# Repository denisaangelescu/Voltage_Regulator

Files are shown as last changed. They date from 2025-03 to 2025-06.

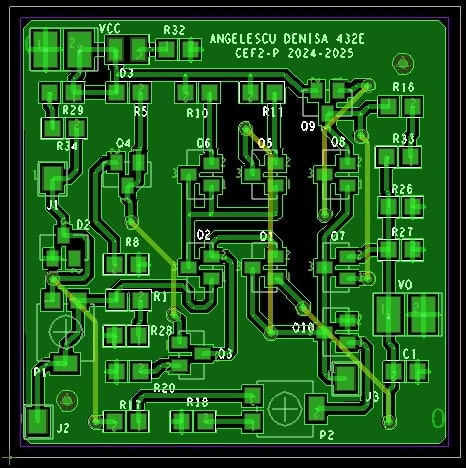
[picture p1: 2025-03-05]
Layout/layout.jpg

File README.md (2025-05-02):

Designed a voltage stabilizer with a series regulation element, ensuring an adjustable output voltage (2V-2.5V) with low thermal drift (<2mV/°C) and high open-loop gain (>200) for stability and precision. The circuit includes short-circuit and thermal protection, limiting the regulation transistor’s temperature to 100°C and the maximum current to 0.4A. Manually calculated component values, performed analytical validation, and simulated the design in OrCAD. Created a PCB layout with SMD components, awaiting fabrication for physical testing.

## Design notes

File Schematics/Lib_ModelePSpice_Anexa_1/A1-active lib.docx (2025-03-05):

77 | 4148 | (LINK) (http://www.tme.eu/ro/details/1n4148-0805/diode-universale-smd/dc-components/cd4148ws0805c/) | 1N4148-0805
79 | 2.7V | (LINK) (http://www.tme.eu/ro/details/bzx84c2v7/diode-zener-smd/on-semiconductor/bzx84c2v7lt1g/) | BZX84C2V7
80 | 5.1V | (LINK) (http://www.tme.eu/ro/details/bzx84c5v1/diode-zener-smd/nxp/bzx84-c5v1215/) | BZX84C5V1
81 | 5.6V | (LINK) (http://www.tme.eu/ro/details/bzx84c5v6/diode-zener-smd/nxp/bzx84-c5v6215/) | BZX84C5V6
82 | 6.2V | (LINK) (http://www.tme.eu/ro/details/bzx84c6v2/diode-zener-smd/nxp/bzx84-c6v2215/) | BZX84C6V2
83 | 6.8V | (LINK) (http://www.tme.eu/ro/details/bzx84c6v8/diode-zener-smd/nxp/bzx84-c6v8215/) | BZX84C6V8
84 | 8.2V | (LINK) (http://www.tme.eu/ro/details/bzx84c8v2/diode-zener-smd/nxp/bzx84-c8v2215/) | BZX84C8V2
85 | 10V | (LINK) (http://www.tme.eu/ro/details/bzx84c10/diode-zener-smd/nxp/bzx84-c10215/) | BZX84C10
86 | PNP | (LINK) (http://www.tme.eu/ro/details/bc856b.215/tranzistori-smd-pnp/nxp/) | BC856B
87 | NPN | (LINK) (http://www.tme.eu/ro/details/bc846b.215/tranzistori-smd-npn/nxp/) | BC846B
89 | N-JFET | (LINK) (http://www.tme.eu/ro/details/mmbfj309lt1g/tranzistori-canal-n-smd/on-semiconductor/) | MMBFJ309LT1G
90 | P-JFET | (LINK) (http://www.tme.eu/ro/details/mmbfj177lt1g/tranzistori-canal-p-smd/on-semiconductor/) | MMBFJ177LT1G
91 | NPN | (LINK) (http://www.tme.eu/ro/details/bc817-25-dio/tranzistori-smd-npn/diotec-semiconductor/bc817-25/) | BC817-25-DIO
93 | PNP | (LINK) (http://www.tme.eu/ro/details/bc807-25-dio/tranzistori-smd-pnp/diotec-semiconductor/bc807-25/) | BC807-25-DIO
94 | NPN | (LINK) (http://www.tme.eu/ro/details/mjd31cg/tranzistori-smd-npn/on-semiconductor/) | MJD31CG
96 | PNP | (LINK) (http://www.tme.eu/ro/details/mjd32cg/tranzistori-smd-pnp/on-semiconductor/) | MJD32CG
97 | Nmos | (LINK) (http://www.tme.eu/ro/details/irfr120npbf/tranzistori-canal-n-smd/international-rectifier/) | IRFR120NPBF

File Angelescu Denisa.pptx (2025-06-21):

## Circuite Electronice Fundamentale 2 – Proiect (CEF2-Pr)

Tema: Stabilizator de tensiune cu ERS

Student: Angelescu Denisa Grupa 432E

## Date de proiectare

Să se proiecteze și realizeze un stabilizator de tensiune cu ERS având următoarele caracteristici:
N = 1
- Tensiunea de ieșire reglabilă în intervalul: - 2 ÷ 2,5 [V]
- Element de reglaj serie;
- Sarcina la ieșire 50[Ω];
- Deriva termică < 2mV/˚C;
- Protecție la suprasarcină prin limitarea temperaturii tranzistorului element de reglaj serie la 100 ˚C și a curentului maxim la 0,4A;
- Tensiune de intrare în intervalul: - 4 ÷ 4,5 [V]
- Domeniul temperaturilor de funcționare: 0 ÷ 70 ˚C (verificabil prin testare în temperatură);
- Amplificarea în tensiune minimă (în buclă deschisă) a amplificatorului de eroare: minim 200;
- Semnalizarea prezenței tensiunilor de intrare/ieșire cu diodă de tip LED.

## Schema bloc

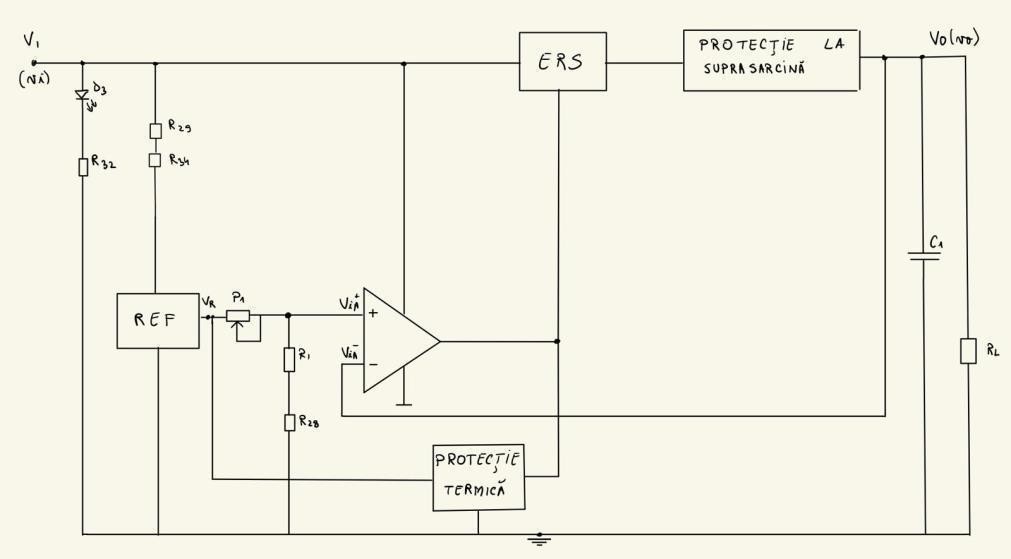
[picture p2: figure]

- D3, R32: Led de semnalizare, indică prezența tensiunii de intrare
- R29, R43: Asigură curentul minim prin REF
- REF (Referință de Tensiune): Creează o tensiune stabilă utilizată ca referința pentru comparație în amplificatorul de eroare
- P1, R1, R28: Divizor de tensiune

- Amplificator de eroare: Compară fracțiunea din tensiunea de ieșire cu tensiunea REF și generează un semnal pentru a controla elementul de reglare
- ERS (Element de reglare în serie): Reglează tensiunea de ieșire în funcție de semnalul primit de la amplificatorul de eroare
- Protecție termică: Protejează circuitul prin dezactivarea acestuia dacă temperatura depășește un nivel critic
- Protecție la suprasarcină: Previne deteriorarea circuitului prin limitarea curentului atunci când acesta depășește un prag specific
- Condensatorul C1: Stabilizează tensiunea de ieșire, eliminând fluctuațiile rapide sau variațiile datorate încărcării sarcinii

## Schema electrică

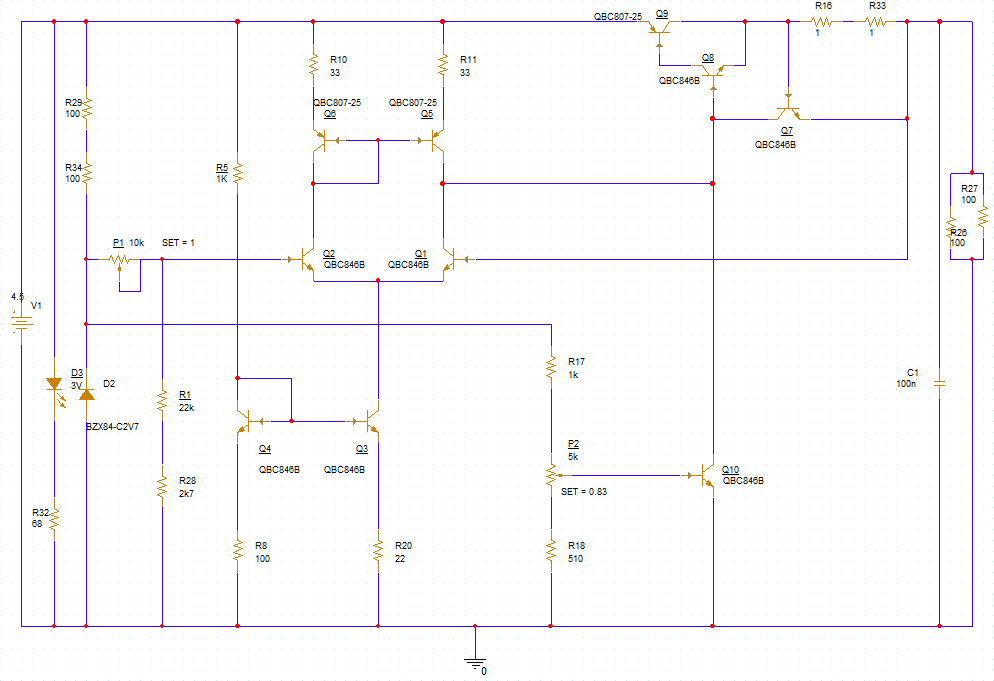
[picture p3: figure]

Reacția este realizată printr-un fir, iar tensiunea de la baza tranzistorului de control este direct legată de tensiunea de ieșire. Diferența dintre tensiunile din bazele tranzistorilor din intrările diferențiale creează un dezechilibru în curenții lor, care ajusteaza ERS pentru a stabiliza tensiunea de ieșire. Perechea Sziklai este mai eficientă decât Darlington pentru tensiuni mici, datorită căderii de tensiune mai reduse (0.6V față de 1.2V)

## Simulări

Tensiuni

Curenți

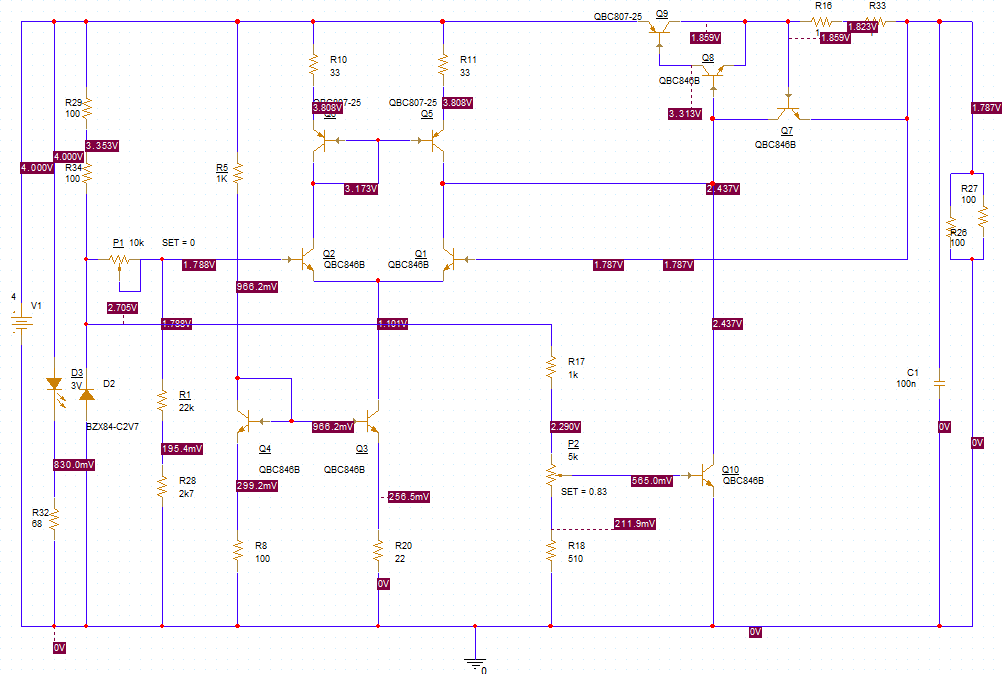
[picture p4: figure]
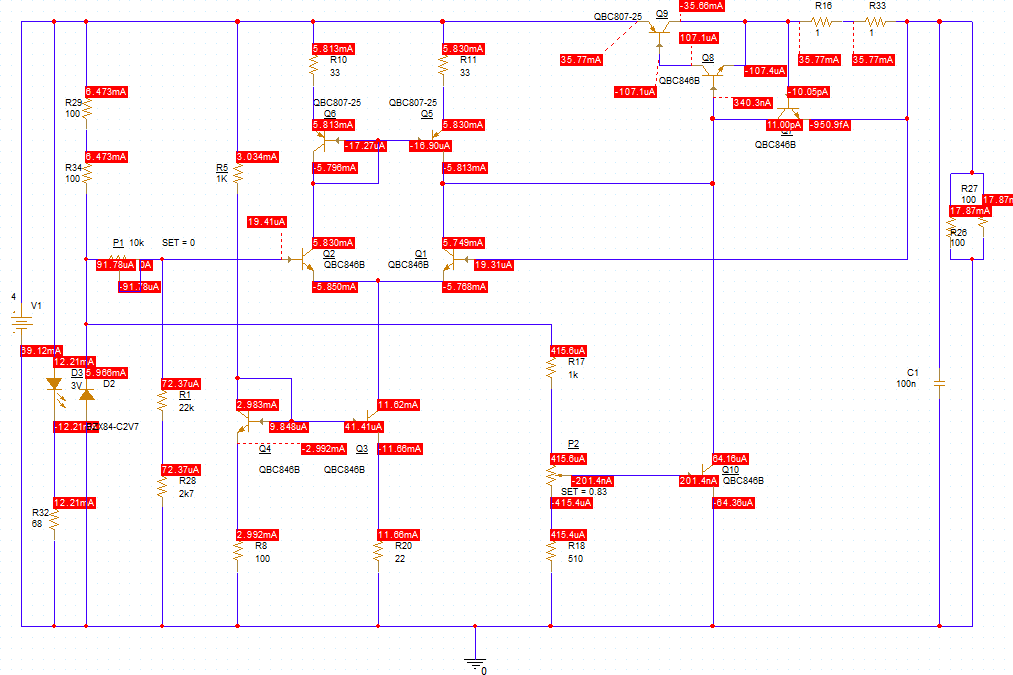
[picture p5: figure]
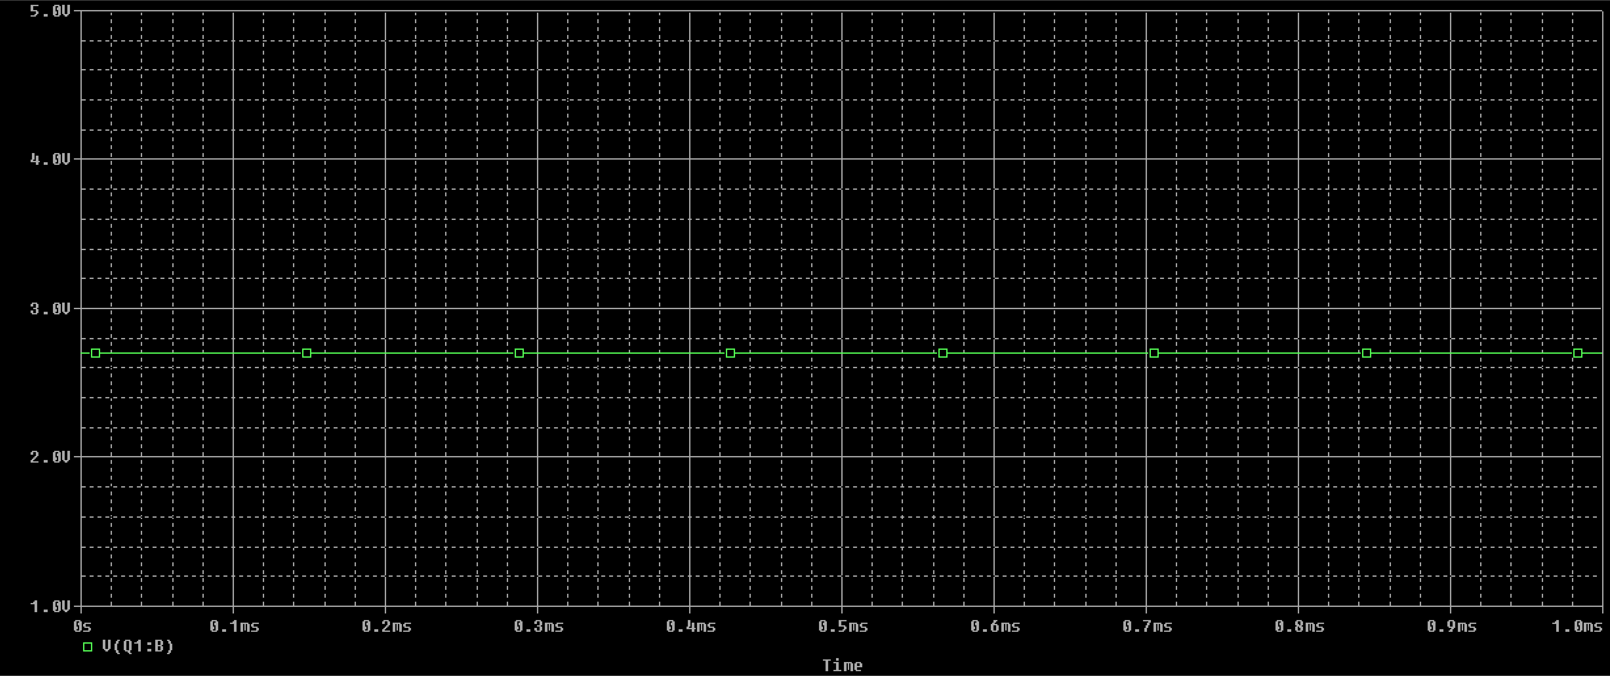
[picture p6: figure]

Variația Vout în timp

## Simulări

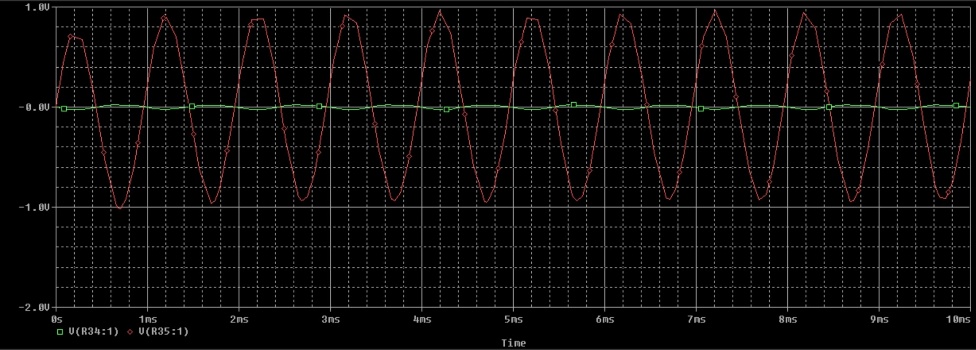
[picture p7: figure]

PSRR

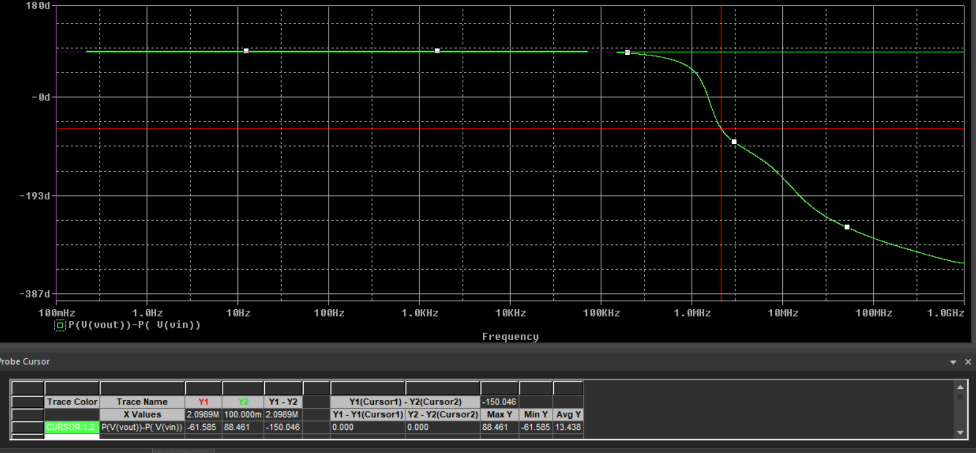
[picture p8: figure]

Faza amplificării

## Layout

Potențiometrele au fost poziționate la marginea plăcii pentru a permite reglaj ușor, fără a interveni în alte zone ale circuitului, iar conectorii de intrare și ieșire sunt amplasați pe exterior pentru măsurători simple și conectare rapidă. Tranzistoarele sunt centralizate și plasate aproape unele de altele pentru a menține caracteristici termice uniforme și a evita variațiile de funcționare. Pentru a reduce pierderile de semnal și interferențele, componentele critice, precum dioda Zener și rezistorii de referință, sunt plasate aproape de amplificatorul diferențial.
Am ales un traseu cu lățime de 18 mils pentru a evita supraîncălzirea și deteriorarea placii. Traseele mai late reduc impedanța și îmbunătățesc stabilitatea semnalelor, asigurând o funcționare mai precisă a circuitului.

Top

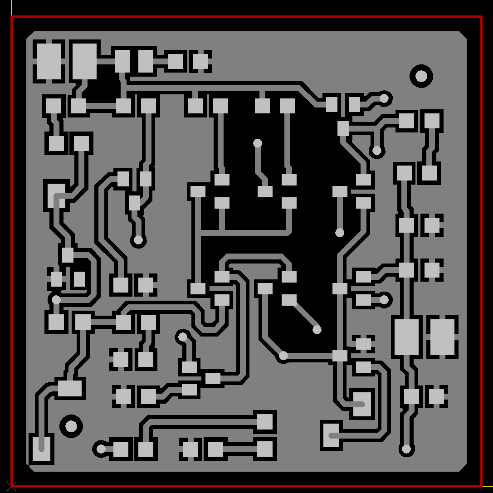
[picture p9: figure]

Bottom

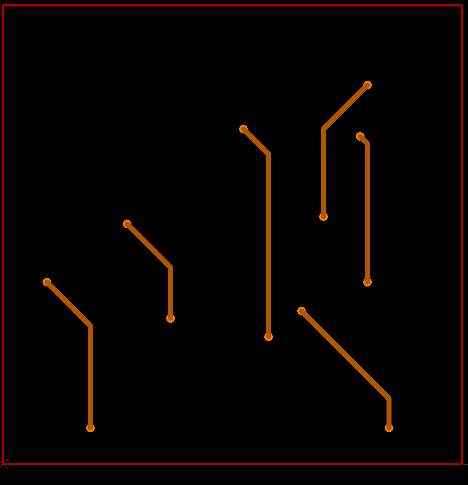
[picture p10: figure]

## Fotografii din etapa de echipare a modulului electronic

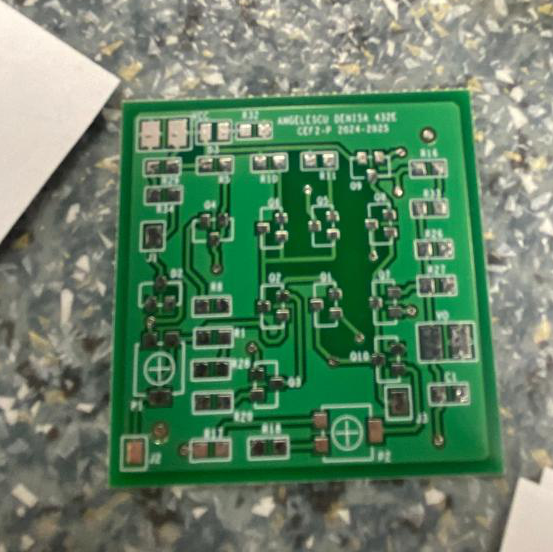
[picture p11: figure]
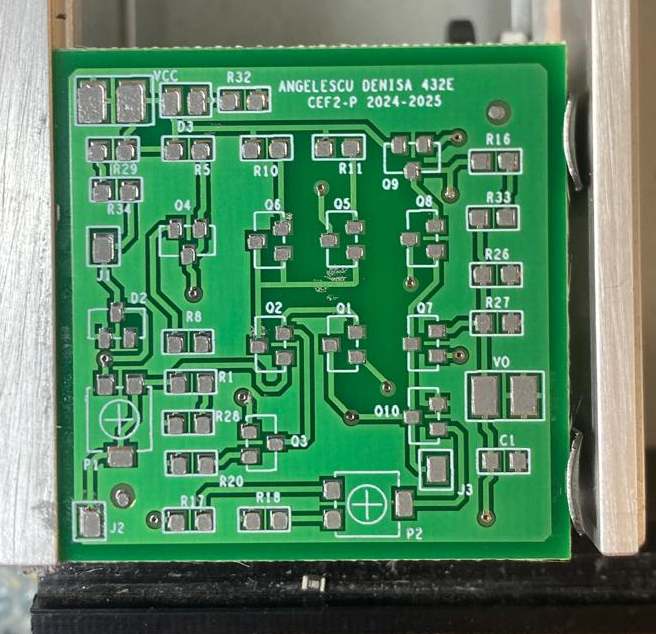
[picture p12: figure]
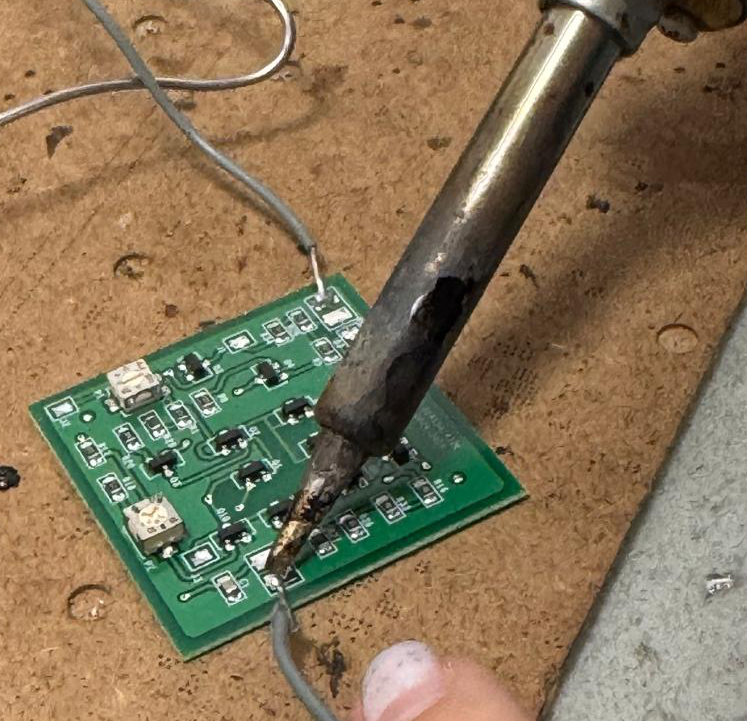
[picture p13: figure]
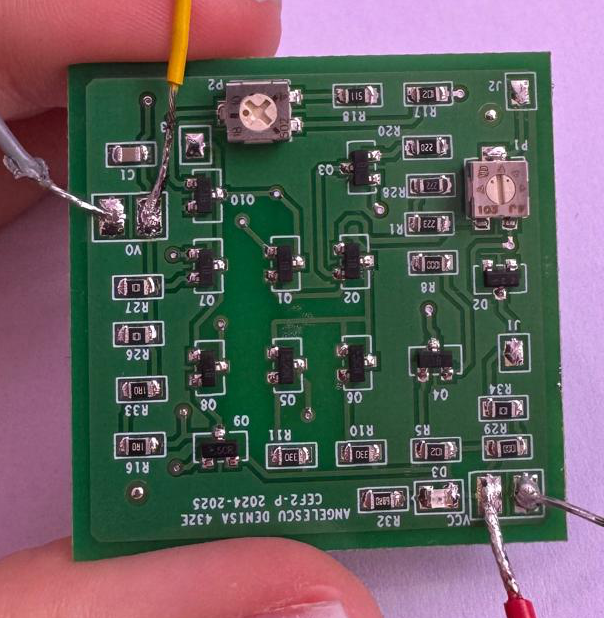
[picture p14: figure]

## Rezultate experimentale

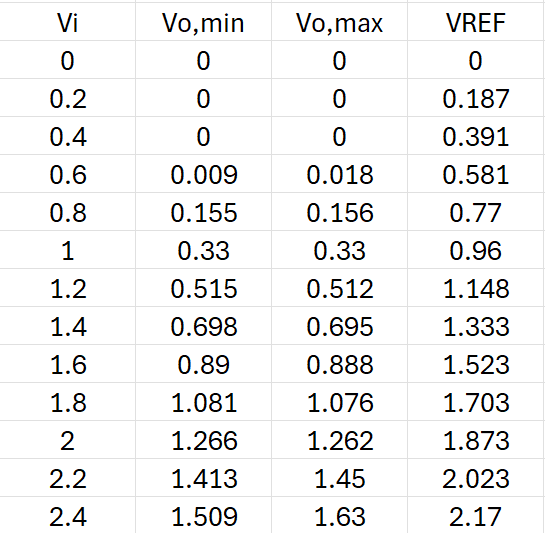
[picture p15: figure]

## Rezultate experimentale

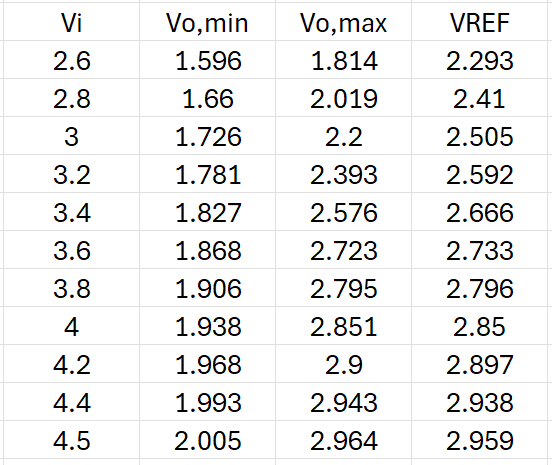
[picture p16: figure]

## Rezultate experimentale

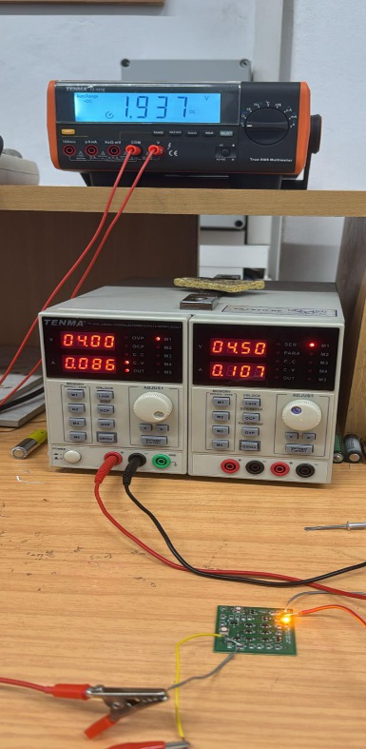
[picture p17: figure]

Vi=4V SET P1 = 0

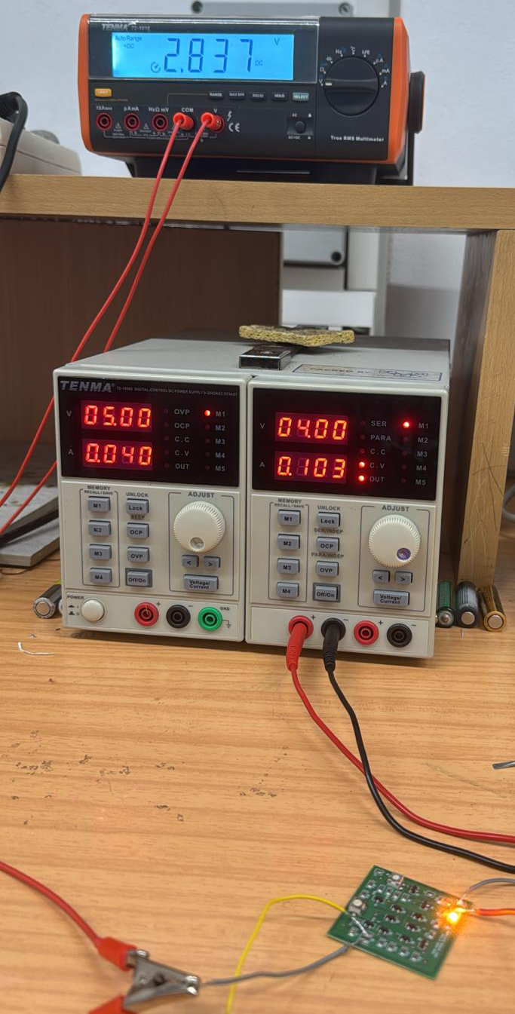
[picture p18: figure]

Vi=4V SET P1 = 1

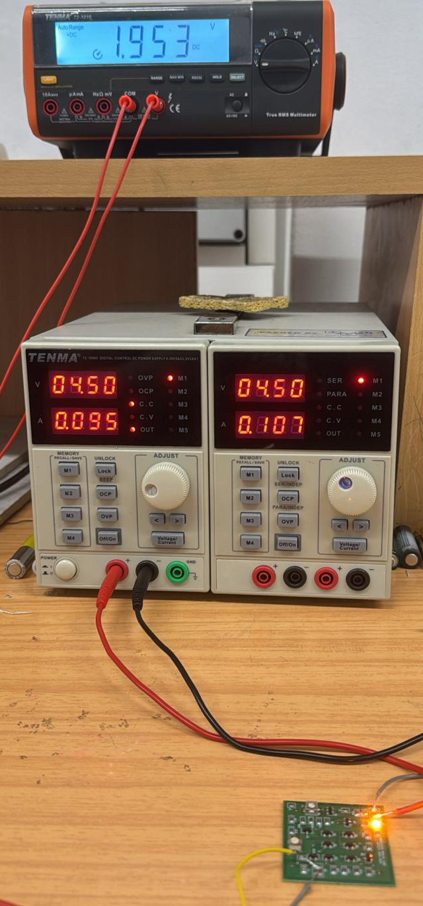
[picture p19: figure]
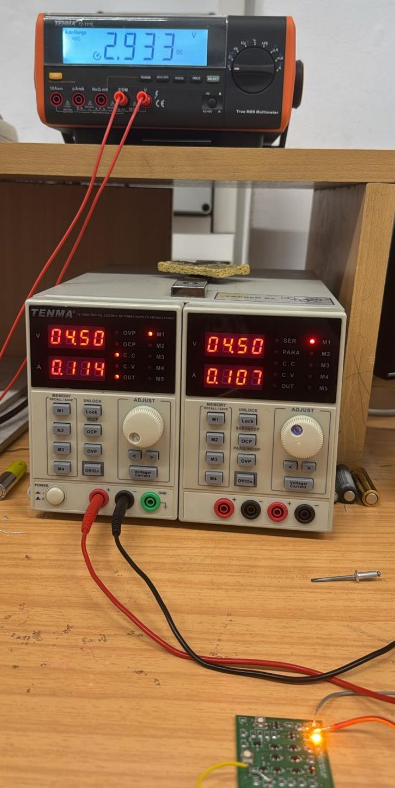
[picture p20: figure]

Vi=4V SET P1 = 0

Vi=4V SET P1 = 0

## Rezultate experimentale

- Tabel comparativ

Cerințe impuse | Rezultate simulări | Rezultate măsurători
OUT: 2 ÷ 2.5V | 1.75 ÷ 2.71V | 1.938 ÷ 2.964V
Deriva termică: 2mV/˚C | 0.3mV/˚C
Protecție limitarea temperaturii: 100˚C | 105˚C
Curent maxim: 0.4A | 0.37A
Amplificare buclă deschisă: 200 | 1163

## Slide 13

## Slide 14

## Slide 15

## Concluzii

- În urma folosirii unei diode mai mare de 2.7V, tensiunea de ieșire a avut o altă valoare față de intervalul specificat de temă.
- Din cauza toleranțelor dispozitivelor, există mici variații între valorile obținute în simulator și cele obținute în realitate.
- O îmbunătățire a proiectului constă în folosirea unor dispozitive cu toleranțe mult mai mici, care să nu influențeze atât de mult valorile reale.

## Cunoștințe dobândite:

- Competențe de simulare în Orcad: realizarea schemei electrice, setarea condițiilor inițiale și interpretarea corectă a rezultatelor.
- Proiectarea PCB-ului: amplasarea componentelor conform regulilor de proiectare (distanțe de izolație, dimensiuni, trasee etc.), definirea straturilor (layere) și generarea fișierelor Gerber.
- Documentare tehnică: căutarea și interpretarea fișelor tehnice (datasheet-uri) pentru tranzistoare, diode Zener, rezistențe și condensatoare.

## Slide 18

- Părți bune:
- Proiectul a fost aplicativ și a consolidat cunoștințele teoretice într-un mod practic.
- Simularea și testarea în realitate au fost corelate, permițând validarea modelului teoretic.
- Părți slabe:
- Ar fi fost util ca materia de CIA (Circuite Integrate Analogice) să fie predată înainte de proiect, pentru a avea cunoștințele necesare realizării unor circuite mai complexe și eficiente.
- Nu au fost oferite exemple complete de proiecte deja testate ca referință (doar parțial).
- Organizarea a fost una bună. (nu aș schimba nimic in organizare)

## Discipline studiate utile în realizarea proiectului

- Bazele electrotehnicii 1
- Bazele electrotehnicii 2
- Dispozitive electronice
- Componente și circuite pasive
- Grafică asistată de calculator – Tehnici CAD pentru electronică
- Circuite electronice fundamentale
- Circuite integrate analogice (doar primele 6 săptămâni, întrucât acesta a fost primul deadline pentru schema electrică)

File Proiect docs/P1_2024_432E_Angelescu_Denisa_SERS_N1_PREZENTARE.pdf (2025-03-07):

Universitatea Națională de Știință și Tehnologie POLITEHNICA București

Facultatea deElectronică, Telecomunicațiiși Tehnologia Informației

Specializarea MON

## Circuite Electronice Fundamentale 2 – Proiect

## Stabilizator cu ERS

Coordonatori: Drăghici Florin

Pantazică Mihaela

Student: Angelescu Denisa Andreea

Grupa: 432E-MON

Anul: 2024-2025

## Cuprins

### 1. Tema Proiectului | pg. 3 2. Schema Bloc | pg. 4 3. Schema Electrică | pg. 6 4. Componenta Circuituluiși Calcule de Dimensionare | pg.7 5. Simulări în OrCAD | pg.12 6. Calcul Analitic | pg.21 7. Layout | pg.33 8. Componente | pg.39 9. Bibliografie | pg.40

### Tema proiectului

Se proiectează un stabilizator de tensiune cu element de reglaj serie cu următoarele caracteristici: N=1

- Tensiunea de ieșire reglabilă în intervalul: 2V-2.5V
- Sarcina la ieșire 50Ω
- Deriva termică < 2mV/grad C;
- Protecție la suprasarcină prin limitarea temperaturii tranzistorului element de reglaj serie la 100 grade C și a curentului maxim la 0,4A;
- Tensiune de intrare în intervalul: 4V-4.5V
- Domeniul temperaturilor de funcționare: 0-70 grade C (verificabil prin testare în temperatură);
- Amplificarea în tensiune minimă (în buclă deschisă) a amplificatorului de eroare: minim 200;
- Semnalizarea prezențeitensiunilor de intrare/ieșire cu diodă detip LED.

### Schema Bloc

Se folosește o schemă de stabilizator cu un element de reglare în serie (ERS), care este controlat de un amplificator de eroare. Acest amplificator de eroare compară o fractiune din tensiunea de referință (REF) cu tensiunea preluată de la ieșire printr-o rețea de reacție. Această comparație permite ajustarea tensiunii de ieșire pentru a o menține stabilă, chiar dacă tensiunea de intrare sau sarcina se modifică. În cadrul acestui stabilizator, tensiunea de referință este mai mare decat tensiunea de ieșire.

Înplus, circuitul este echipat cu protecțiipentru a preveni avariile:

1. Protecție la suprasarcină – care evită deteriorarea componenteireglatorului în cazulunui curent prea mare.
2. Protecție termică – care oprește funcționarea dacă temperatura reglatorului depășește un nivel critic.
3. LED-ul – care indică prezența tensiunii la intrare, semnalizând că circuitul este alimentat corect.

Astfel, acest stabilizator este capabil să regleze tensiunea de ieșire și să ofere protecții esențiale pentru funcționarea sigură și stabilă a circuitului.

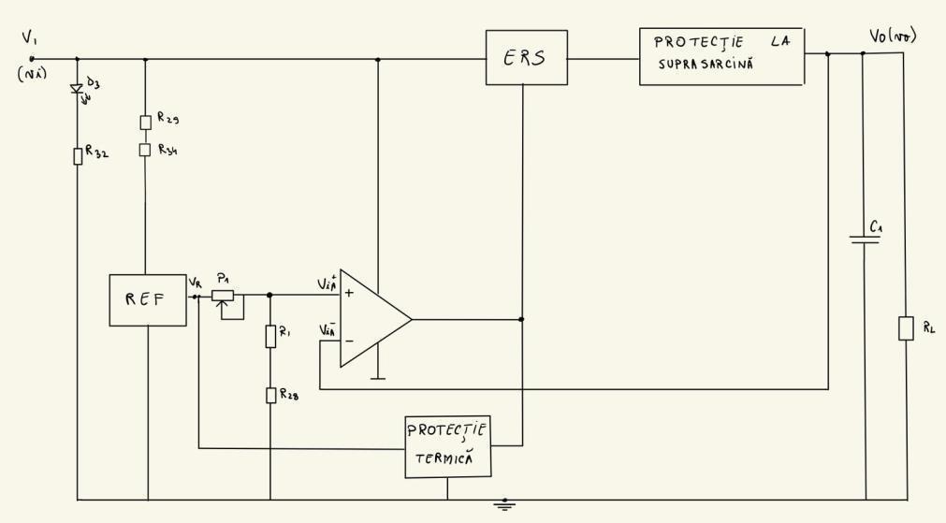
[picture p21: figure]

Fig. 1 Schema Bloc

În schema dată, la intrarea neinversoare a amplificatorului de eroare este aplicată o fracțiune din tensiunea de referință (REF), ajustabilă prin divizorul de tensiune format din rezistențe și potențiometru. La intrarea inversoare a amplificatorului de eroare este conectat direct un fir care aduce semnalul de eroare la ieșirea circuitului, preluat prin reacție negativă. Amplificatorul de eroare compară aceste două semnale și generează o comandă pentru elementul regulator serie (ERS) pentru a stabiliza tensiunea de ieșire Vout. Dacă, spre exemplu, Vout crește, va crește și tensiunea de pe intrarea inversoare. Știm că ieșirea opamp-ului este amplificarea înmulțită cu V+ - V- , deci va scădea tensiunea de la ieșirea opamp-ului. Va scădea și tensiunea VBE de la tranzistorul din elementul de reglaj serie, deci și curentul Ic = IS*exp(VBE/VT) va scădea, astfel, indiferent dacă este amplificat cu β sau nu (dacă sunt mai mulți tranzistori în configurația elementului de reglaj), curentul care va ajunge prin RL va fi mai mic, deci și VOUT va scădea -> astfel se realizează stabilizarea tensiunii de la ieșire.
Văzut simplificat, circuitul poate fi interpretat ca un amplificator cu doua etaje de feedback, cu o fracțiune din tensiunea de referință la intrare. Primul etaj este opamp-ul, iar al doilea este un emitor comun. Acesta poate “conduce” curent mare către sarcină, depinzând de tenciunea VCE, ce se transpune în cădere de putere.

Tensiunea de intrare de obicei are un riplu, ulterior atenuat de stabilizator, fapt văzut în simulări. Acuratețea valorii tensiunii de ieșire este dată de raportul rezistorilor și de acuratețea absolută a tensiunii de referință.
În plus, circuitul include protecție la suprasarcină și protecție termică pentru a preveni supraîncălzirea, iar un LED semnalizează prezența tensiunii la intrare, indicând că alimentarea este activă. În schema dată, condensatorul ceramic SMD 0805 C1 joacă un rol esențial în stabilizarea tensiunii de ieșire, mai ales în cazul în care sarcina necesită șocuri de curent (se comportă ca o sursă locală de curent). Acesta acționează ca un rezervor de energie, compensând rapid variațiile curentului și asigurând o funcționare stabilă a circuitului. Toți rezistorii sunt de tip SMD chip 0805 și potențiometrele liniare simplă tură de tip SMD.

### Schema Electrică

Fig. 2 Schema Electrică

Amplificator de eroare: Q1, Q2, Q5, Q6, R10, R11 șigeneratorul de curent: Q3, Q4, R8, R20

Element de reglaj serie: Q8, Q9

Referința de tensiune: D2

Divizor detensiune: P1, R1, R28

Rețea de reacție negatuvă: fir

Protecție termică: Q10, R17, P2, R18

Protecție la suprasarcină: Q7, R16, R24, R25

Circuit pentru semnalizarea tensiunii de la intrare: led D3, R32

Rezistor de sarcină: gruparea R26, R27

### Componența Circuitului și Calcule de Dimensionare

1. Amplificatorulde eroare

Amplificatorul de eroare are funcția principală de a măsura diferența (eroarea) dintre două semnale: o fracțiune din tensiunea de referință și tensiunea de ieșire. Această diferență, numită eroare, este apoi amplificată și utilizată pentru a ajusta circuitul astfel încât să elimine eroarea și să stabilizeze tensiunea de ieșire.

Tranzistorul Q4 care este în configurație de diodă stabilește curentul prin oglinda Q4-Q3, Q3 fiind clientul. Acesta polarizeaza etajul diferențial format din Q1-Q2 (grilele la referință, respectiv la tensiunea de ieșire; sursele în scurt) și reprezină sursa de curent pentru etaj. Aici există o sarcină activă dată prin Q6-Q5, iar rezistențele R10-R11 limitează curentul care trece pe cele două ramuri proportional. Numărând etajele sursă comună de la intrări până la ieșire, Q1 este borna inversoare și Q2 este borna neinversoare.

Curentul prin tranzistoarele din etajul diferențial (Q1 si Q2) este dictat de cel din Q3, care este direct proporțional cu cel prin Q4. Q4 se comportă ca o diodă VCE = 0.66V, iar pentru a avea IC = 3mA la Vin = 4V, am ales R5 = 1kΩ și rezistor din oglinda de curent R8 = 100Ω, iar la 4.5V va fi 3.4mA. Datorită proporționalității celor două rezistente din oglindă (R8 si R20) și curenții IC3 și IC4 vor fi proporționali, deci egali cu 11.6mA la Vin = 4V, iar pentru 4.5V vor fi 13.6mA.

Pentru ca tranzistorii Q1 și Q2 sunt de același tip QBC846B, avem oglinda de curent dată de Q5, Q6 și rezistențele egale cu 33Ω, curenții prin aceștia vor fi egali cu Ice3 /2. Tranzistorii Q3 și Q4 sunt de acelasi tip QBC846B, iar Q5 și Q6 de tip QBC807-25 pentru ca amplificarea in bucla deschisa sa fie mare (modelată prin etajele sursă comună, respectiv sarcină distribuită).

Ic1 = IC2 = IC3 / 2 = 5.8mA pentru Vin = 4V, iar pentru 4.5V vor fi 6.8mA

Baza tranzistorului Q2 primește semnalul de referință, iar baza tranzistorului Q1 primește un semnal proporțional cu tensiunea de ieșire. Diferența dintre aceste două tensiuni creează un dezechilibru în curenții prin cele două tranzistoare (Q1 și Q2), iar acest dezechilibru este utilizat pentru a controla următorul etaj din stabilizator. Dacă tensiunea de ieșire începe să devieze de la valoarea dorită, diferența de tensiune de la intrările amplificatorului diferențial crește. Aceasta modifică curenții prin Q1 și Q2, care, prin reacție, ajustează curentul prin tranzistoarele de putere din stabilizator, restabilind tensiunea de ieșire.

Potențialul din baza tranzistorului Q2 | în funcție de SET-ul
potențiometrului P1 | avem SET=0 -> 1.772V și pentru SET=1 ->

Fig. 3

2.716V (potențial dat de tensiune de referință înmulțită cu un factor de divizare dat de potențiometru). Astfel, potențialul din emitorul lui Q2 va fi 1V sau 2V, iar tensiunea VCE3 = VE2 – IC3*R20 = 0.85mV > 0.66mV sau 1.85V > 0.66mV (este în RAN în cele două cazuri nefavorabile).

2. Elementulde reglajserie

Perechea Sziklai are câteva avantaje esențiale față de Darlington. În primul rând, introduce o cădere de tensiune mai mică, de doar 0.6V, în comparative cu 1.2V la Darlington, care o face mai eficientă pentru tensiuni mici, cum este cazul meu.

De asemenea, disipează mai puțină putere, ceea ce reduce încălzirea tranzistoarelor. Curentul de bază necesar este mult mai mic datorită câștigului total ridicat, reducând solicitările asupra circuitelor anterioare. În plus, oferă o stabilitate termică mai bună, fiind mai puțin afectată de creșterea temperaturii. Aceste avantaje o fac ideală pentru aplicații cu eficiență ridicată și alimentare redusă.

În cel mai defavorabil caz când Vin = 4.5V, Q9 suportă un curent de 54.17mA și o putere de 92mW. Alegem Q9 de tipul QBC807-25 și Q8 de tipul QBC846B.

Presupunem că stabilizatorul nu are nevoie de protecție la suprasarcină, deci potențialul în emitorul lui Q8 este în intervalul 2V-2.5V. Baza aceluiași tranzistor este legată la ieșirea din amplificatorul de eroare, potențialul din baza lui Q8 este egal cu potențialul din emitorul lui Q8 adunat cu 0.66mV (Q8 este in RAN).

Fig. 4

3. Referința de tensiune și divizorul de tensiune

Referința de tensiune este formată dintr-o diodă Zener de tip BZX84-C2V7 cu tensiunea de străpungere constantă de aproximativ 2.7V în condițiile în care este alimentată cu un curent minim de 5mA . Pentru acest tip de diode (dacă sunt polarizate la curent constant) se constată un drift termic foarte mic în intervalul 0-70⁰C. Împreună cu potențiometrul P1 de 10kΩ și rezistențele R1 de 22kΩ și R28 de 2.7kΩ formează un divizor de tensiune ce reprezintă fracțiunea cu care este comparată tensiunea de ieșire a stabilizatorului. Curentul prin R29 vreau să fie de aproximativ 6.5mA, ca prin Zener să fie de minim 5mA.

R29=(Vin-Vz)/6.5=aprox. 200Ω (vom inseria două rezistențe de 100Ω cu toleranțele de ±5%).

Curentul prin R29 este aproximativ 6.5mA (pentru Vin=4V – caz cel mai defavorabil) sau 9mA (pentru Vin=4.5V).

Fig. 5

Curenții prin P1 și cel care ,,duce” înspre circuitul de protecție termică nu vor fi neglijabili. Curentul prin baza lui Q2 neglijabil => IP1=Vz/(P1+R1+R28) = 90uA sau 126uA la valori limită ale potențiometrului. Curentul care ,,trece” în circuitul de protecție termică va fi egal cu Vz/(P2+R17+R18) = 415uA (curentul prin baza lui Q10 neglijabil).

Astfel, Iz va fi IR4-IP1-Iprotecție termică = 6.5mA-126uA-415uA=5.9mA (am considerat cele mai defavorabile cazuri), iar 5.9mA > Izmin=5mA.

Potențialul | în | nodul | terminalului | din | dreapta | al | potențiometrului | P1
( V = Vz*(R1+R28)/(R1+R28+P1) caz ideal când consideram curenții zero) este tensiunea din intrarea neinversoare a amplificatorului diferențial, care mai departe este egală cu tensiunea din intrarea inversoare, iar cum reacția este formată dintr-un fir, va fi egală cu tensiunea de ieșire a circuitului în cazul în care se realizează stabilizarea. Astfel că valorile limită ale Vout sunt date de valorile limită ale lui P1. Calculul intervalului tensiunii de la ieșirea stabilizatorului: pentru SETP1 = 0 => Vout = V1
- IP1*P1 = 1.772V șipentru SETP1=1 => Vout = 2.716V.
4. Rețeaua de reactive negativă

Din cauza faptului că tensiunea de referință este de 2.7V, tensiunea maximă de ieșire este de 2.5V și pentru că în realitate trebuie să am o anumită eroare pentru a asigura funcționarea corectă a circuitului, am ales ca reacția să fie formată dintr-un singur fir, iar valorile limită ale tensiunii din baza lui Q2 date de SET-ul potențiometrului P1 sunt valorile tensiunii de la ieșire. Factorul de reacție este 1.

SETP1 =0 => Vout = V1 - IP1*P1 = 1.771V

SETP1=1 => Vout = V1 - IP1*P1 = 2.716V

Fig. 6

5. Circuitulde protecție termică

Am ales potențiometrul P2 de 5kΩ cu toleranța +-20% pentru a avea un interval mai mare de variație a tensiunii bază-emitor a tranzistorului Q10. În cazurile limită ale SET-ului potențiometrului 2, VBE10 aparține intervalului [211.9 ; 742.0] mV. Pentru protecția termică la 100 de grade Celsius, este nevoie să se ajusteze potențiometrul, ținând cont că tensiunea VBE10 variază cu 2mV/grad Celsius. Când temperatura crește și ajunge la 100 de grade Celsius, Q8 intră în conducție pentru:

∆t=100-25=75 gradeCelsius => VBE10 = 0.687V – 2mV*75 = 537mV

Dacă temperatura scade la 0 grade Celsius, VBE10 = 687mV + 2mv*25 = 737mV

Astfel, potențiometrul ajută in cazul erorilor aleatorii de fabricație, în cazul în care există o abatere de la cazul ideal, cel calculat de mine.

Fig. 7

6. Circuitulde protecție la suprasarcină

IO,lim = VBE7/R = 0.4A => R = 1.66Ω, iar ca valoarea standard am ales 2Ω. Astfel, pentru curenți mai mici de 0.34A nu intră în funcțiune circuitul de protecție la suprasarcină, adica tranzistorul Q7 este în blocare.

Când curentuldepășește 0.34A, tranzistorul intră în conductie.

Fig. 8

Astfel, din teorie se poate trasa graficultensiunii de ieșire din stabilizator în funcție de curent:

Fig. 9

7. Circuit pentru semnalizarea tensiunii de la intrare

Am ales diode led OF-SMD2012B de culoare albastră, cu tensiunea de conducție 3V. Pentru a se aprinde led-ul în cazul cel mai nefavorabil (Vin = 4.5V) și să nu depășească curentul maxim, am ales o rezistență standard de 68Ω cu toleranța de +-1%. Astfel, curentul prin led va aparține intervalului [12.21 ; 19.12] mA. Pentru ieșire nu se poate semnaliza tensiunea cu un led din cauza ca Voutmaxim = 2.7V < 3V necesari pentru led.

Fig. 10

### Simulări în OrCAD

I. Simulări pentru a reda stabilitatea tensiunii de la ieșire cu variația tensiunii de la intrare și setarea potențiometrului P1 pentru a vedea intervalul de lucru a lui

Vout :

Fig. 11 Vout= f(Vin) cu SETP1 = 0

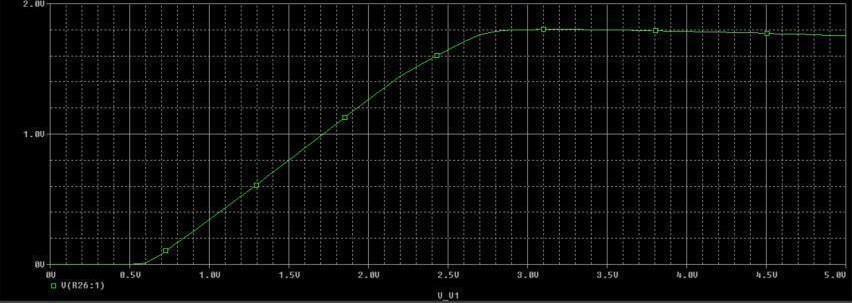
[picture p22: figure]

Tensiunea minima măsurată cu cursorii este de 1.77V care este în intervalul cautat.

Fig. 12 Vout= f(Vin) cu SETP1 = 1

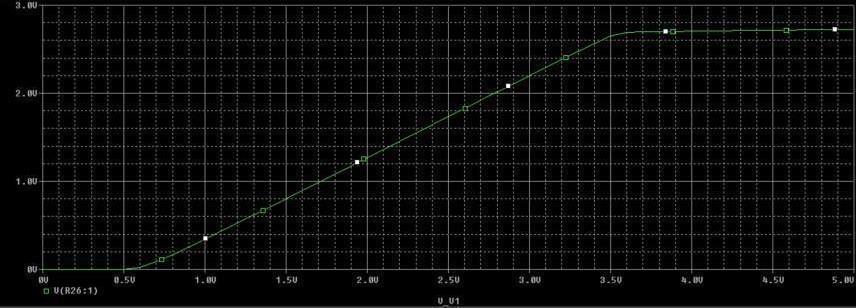
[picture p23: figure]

Tensiunea maximă măsurată de cursorii este de 2.71V care este în intervalul cautat.

Se poate observa că Vout este stabilizat și înainte și după intervalul de lucru de [4; 4.5] V pentru Vin. Acest lucru subliniază eficiența configurației cu reacție și a amplificatorului de eroare, care ajustează automat tensiunea de comandă a tranzistoarelor pentru a compensa variațiile din alimentare. Perechea Sziklai contribuie semnificativ la această stabilitate, oferind o cădere de tensiune redusă și un câștig de curent ridicat, asigurând astfel o ieșire constantă, chiar și în condiții defavorabile. Observația că Vout rămâne stabilă indică faptul că proiectarea circuitului este robustă și bine adaptată pentru aplicații care necesită o alimentare sigură și predictibilă.

II. Simulări pentru deriva termică 0-70 grade Celsius pentru valori limită ale Vout:

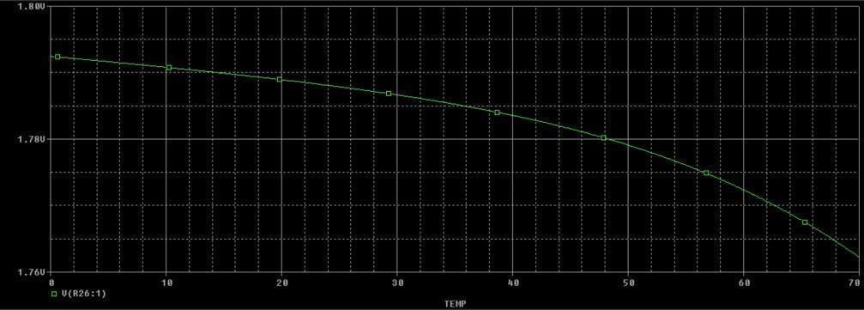
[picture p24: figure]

Fig. 13 Vout= f(Temp) cu SETP1 = 0

Se calculează panta graficului: 0.43mV/grad Celsius.

Fig. 14 Vout= f(Temp) cu SETP1 = 1

Se calculează panta graficului: 0.30mV/grad Celsius.

O pantă mai mică la SETP1=1 sugerează o stabilitate termică mai bună, care face această configurație mai adecvată pentru condiții de mediu variabil. În plus, reglajul fin al potențiometrului contribuie la reducerea sensibilității, iar aceste date subliniază importanța optimizării compensării termice pentru aplicații critice.

III. Simulări pentru variația Vout cu temperatura 0-100 grade Celsius:

Fig. 15 Vin = 4V SETP1 = 0

Fig. 16 Vin = 4V SETP1 = 1

Fig. 17 Vin = 4.5V SETP1 = 0

Fig. 18 Vin= 4.5V SETP1 = 1

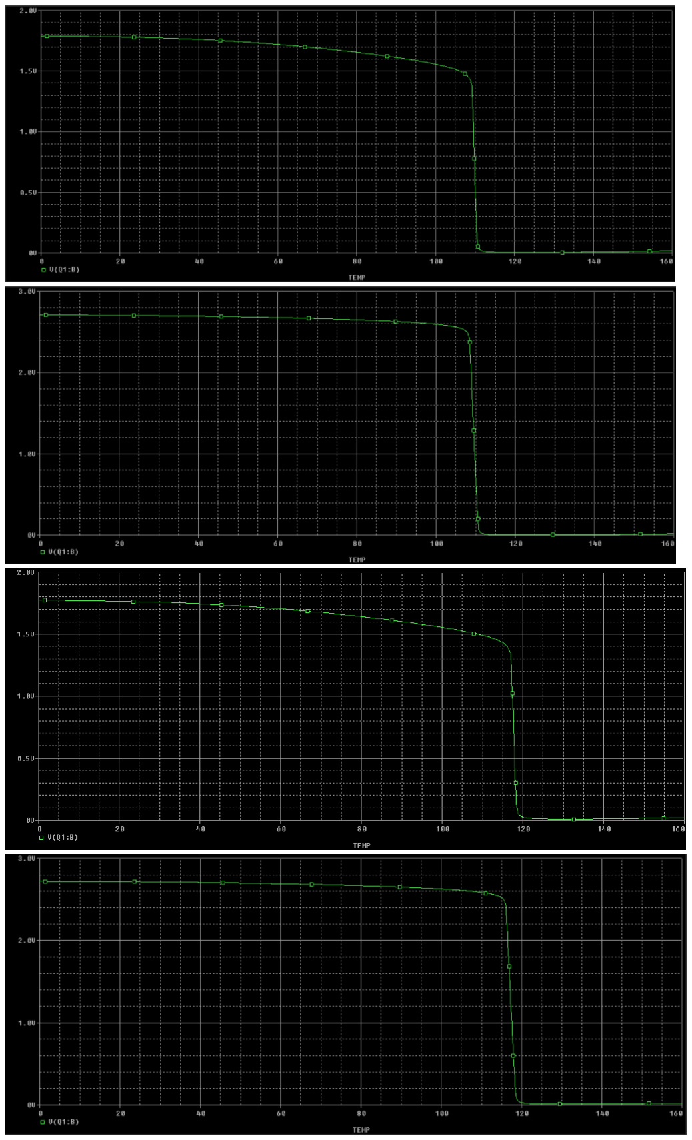
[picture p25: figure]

Simulările arată că Vout rămâne stabilizat în intervalul de temperatură 0–100°C, care demonstrează o bună performanță termică a stabilizatorului în condiții normale de funcționare.

Scăderea bruscă a tensiunii de ieșire observată între 100–120°C indică activarea protecției termice, un mecanism eficient pentru prevenirea supraîncălzirii și protejarea componentelor critice ale circuitului. Intervalul de temperatură poate fi schimbat cu ajutorul potențiometrului P2. Circuitul este protejat și la temperaturi negative. Acest comportament asigură fiabilitatea stabilizatorului în aplicații care pot implica variații mari de temperatură și subliniază importanța proiectării sigure în condiții extreme.

IV. Simulare pentru evidențierea protecției la suprasarcină:


Fig. 19 Schema electrică cu modificările necesare

Pentru a simula IOlim, trebuie să setez rezistorul de sarcină la o valoare foarte mare (astfel curentul de la ieșire va fi foarte mic și nu va influența cu nimic simularea) și să pun la ieșire o sursă de curent DC care variază. Pentru ca tensiunea de iesire să nu scada foarte mult pe tensiuni negative, este limitată de tensiunea dată de dioda D4 (Dbreak).


Fig. 20 Vout = f( I1 )

Graficul indică faptul că la valoarea de 0.37mA a curentului de ieșire, tensiunea Vout scade brusc, marcând punctul în care circuitul intră în regim de protecție. Această scădere indică activarea mecanismului de limitare a curentului IOlim, care previne depășirea curentului maxim admis de stabilizator. Acest comportament este intenționat și protejează tranzistoarele și alte componente critice ale circuitului împotriva supraîncălzirii sau avariei. Scăderea rapidă a tensiunii demonstrează răspunsul eficient al circuitului la atingerea curentului de limitare, asigurând funcționarea corectă a regimului de protecție.

V. Simulare pentru verificarea ca amplificarea în bucla deschisă este a>200:

În această configurație modificată (Fig. 21), circuitul a fost ajustat pentru a analiza răspunsul amplificatorului diferențial fără influența reacției negative. Prin aplicarea unei tensiuni sinusoidale V4 la intrarea inversoare și asigurarea unei tensiuni de curent continuu fixe la intrarea neinversoare, se poate observa modul în care amplificatorul diferențial răspunde variațiilor tensiunii de intrare.

Graficul din Fig. 22 arată că tensiunea de ieșire a amplificatorului are o tranziție abruptă la un anumit prag al tensiunii sinusoidale de intrare. Această caracteristică evidențiază funcția de comparație a amplificatorului diferențial, care începe să devieze rapid atunci când tensiunea aplicată la intrarea inversoare depășește tensiunea de curent continuu de la intrarea neinversoare.

Această simulare demonstrează sensibilitatea amplificatorului diferențial la variațiile semnalului de intrare și este utilă pentru a înțelege cum acesta generează un semnal de control în condiții de funcționare reale. În plus, eliminarea reacției negative permite observarea pură a comportamentului amplificatorului, ceea ce este util pentru calibrarea sau optimizarea răspunsului acestuia. Am ales să pun rezistorii R8 > R20 pentru ca IC3 > IC4, implicit ca și curenții prin diferențial să fie mai mari decât cum erau inițial. Pentru calculul amplificării am folosit faptul ca pentru tranzistorii în configurație sursă comună, formula este -gm*RL, iar gm = 40*IC. Pentru ca amplificarea sa fie mai mare (cerință > 200), o soluție a fost să cresc gm prin curentul care trece prin tranzistorul Q1.

Fig. 21


Fig. 22

Din grafic se calculează panta care semnifică amplificarea în bucla deschisă a amplificatorului: a = ∆Vout / ∆Vin = -1163.28. Semnul negative este justificat, pentru că circuitul este un inversor.

VI. Simulare pentru Raportul de Rejecție a Alimentării (PSRR):

Pentru determinarea PSRR-ului (Power Supply Rejection Ratio), am realizat câteva modificări importante asupra schemei inițiale (Fig. 23). La intrare și ieșire am introdus câte un condensator de 1 nF în serie cu o rezistență de 500 kΩ. Scopul acestei modificări a fost de a limita curentul ce trece prin ramuri la o valoare foarte mică, asigurând în același timp funcționarea corectă a circuitului. Această configurație permite păstrarea componentei alternative a tensiunii și eliminarea parțială a componentei continue, esențială pentru funcționarea stabilizatorului. Sondele de măsurare au fost plasate după condensatoare, astfel încât să putem observa variațiile sinusoidale fără interferența tensiunii continue.


Fig. 23

După implementarea modificărilor, am realizat simularea circuitului pentru a observa comportamentul tensiunilor de intrare și ieșire. Din graficul obținut se poate observa că tensiunea de intrare variază între 0 V și 900 mV în regim sinusoidal, în timp ce tensiunea de ieșire are o variație semnificativ redusă, între 0 V și 13 mV. Aceasta indică o atenuare considerabilă a variațiilor de tensiune de pe linia de alimentare la ieșire, evidențiind performanța circuitului în filtrarea ripple-ului.

Pentru a evalua mai precis performanța stabilizatorului, am calculat PSRR-ul folosind relația:

PSRR = 20*lg ( ∆Vin / ∆Vout)


Fig. 24

Am calculat PSRR ca fiind 20*lg(900/13) = 36.8dB. Această valoare a PSRR evidențiază eficiența circuitului în menținerea stabilității tensiunii de ieșire. Practic, stabilizatorul reduce semnificativ variațiile sinusoidale ale tensiunii de alimentare, cee ace este crucial pentru aplicații care necesită o tensiune stabilă și fiabilă. Simularea și calculul confirmă performanța circuitului și capacitatea acestuia de a funcționa eficient în condiții de alimentare fluctuantă, protejând dispozitivele conectate împotriva perturbațiilor de pe linia de alimentare.

### Calcul Analitic

PSF – tensiune

Fig. 25 Vin= 4V SETP1 = 0

Fig. 26 Vin= 4V SETP1 = 1


Fig. 27 Vin= 4.5V SETP1 = 0

Fig. 28 Vin = 4.5V SETP1 = 1


PSF– curent

Fig. 29 Vin= 4V SETP1 = 0

Fig. 30 Vin= 4V SETP1 = 1


Fig. 31 Vin= 4.5V SETP1 = 0

Fig. 32 Vin= 4.5V SETP1 = 1

PSF– putere

Fig. 33 Vin= 4V SETP1 = 0


Fig. 34 Vin= 4V SETP1 = 1


Fig. 35 Vin= 4.5V SETP1 = 0

Fig. 36 Vin= 4.5V SETP1 = 1





### Layout

Fig. 37 Layer electric TOP

Fig. 38 Layer electric BOTTOM

Fig. 39 Layer neelectric Solder Mask Top

Fig. 40 Layer neeletric Solder Mask


Bottom

Fig. 41 Layer neelectric Silk Screen Top

Fig. 42 TOP + SSTOP

Fig. 43 Layer neelectric Solder Paste

Mask Top

Fig. 44 TOP + SPTOP

Fig. 45 SSTOP + SPTOP + SMTOP


Fig. 46 Layer neelectric Board Outline


Fabrication Drawing

Fig. 47


Fig. 48 DRILL

Fig. 49 SMBOT + DRILL +

BOTTOM


Fig. 50 Layout

### Componente

Nr. Crt. | Total | Denumire | Valoare
1 | 1 | C1 | 100n
2 | 1 | D2 | BZX84-C2V7
3 | 1 | D3 | LED
4 | 1 | P1 | 10k
5 | 1 | P2 | 5k
6 | 7 | Q1,Q2,Q3,Q4,Q7,Q8,Q10 | QBC846B
7 | 3 | Q5,Q6,Q9 | QBC807-25
8 | 1 | R1 | 22k
9 | 2 | R5,R17 | 1k
10 | 5 | R8,R26,R27,R29,R34 | 100
11 | 2 | R10,R11 | 33
12 | 2 | R16,R33 | 1
13 | 1 | R18 | 510
14 | 1 | R20 | 22
15 | 1 | R28 | 2k7
16 | 1 | R32 | 68

## Bibliografie

1. G. Brezeanu, F. Drăghici, Circuite electronice fundamentale, Ed. Niculescu, București, 2013;
2. G. Brezeanu, F. Draghici, F. Mitu, G. Dilimot, Circuite electronice fundamentale - probleme, Editura Rosetti Educational, Bucuresti, editia II–2008;
3. G. Brezeanu, F. Draghici, F. Mitu, G. Dilimot, Dispozitive electronice - probleme, Editura Rosetti Educational, Bucuresti, 2009;
4. Sedra Smith, MicroelectronicCircuits – seventh edition, Editura Oxford UniversityPress
5. Norocel Codreanu, Ciprian Ionescu, Mihaela Pantazică, Alina Marcu, “Tehnici CAD de realizare a modulelor electronice – suport de curs și laborator”, Editura Cavallioti, PIM, Iași, Decembrie 2017

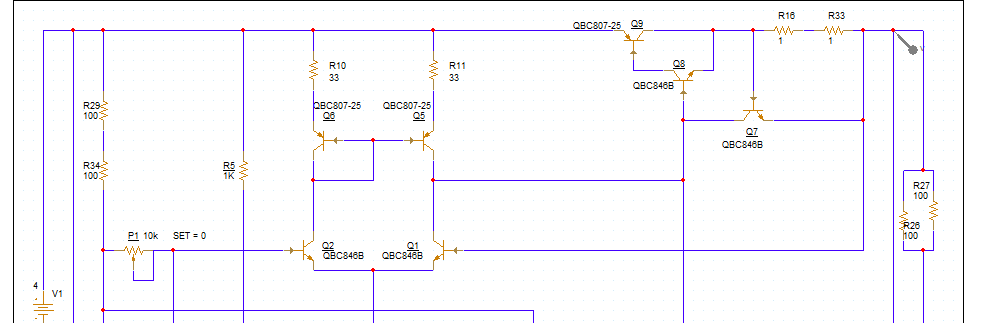
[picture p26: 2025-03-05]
Schematics/PROIECT_OrCAD/P1_2024_432E_ANGELESCU_DENISA_SERS_N1_ORCAD.png

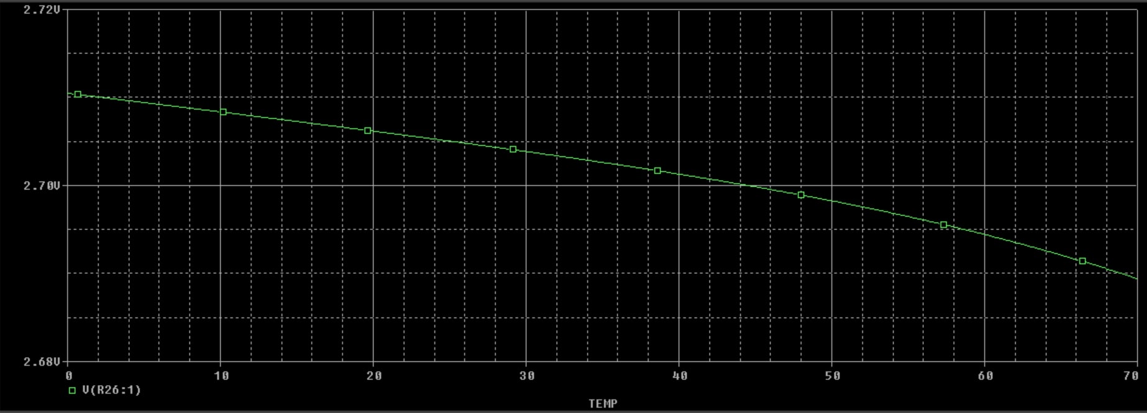
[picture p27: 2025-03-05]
Simulations/deriva_termica_set=1.jpg

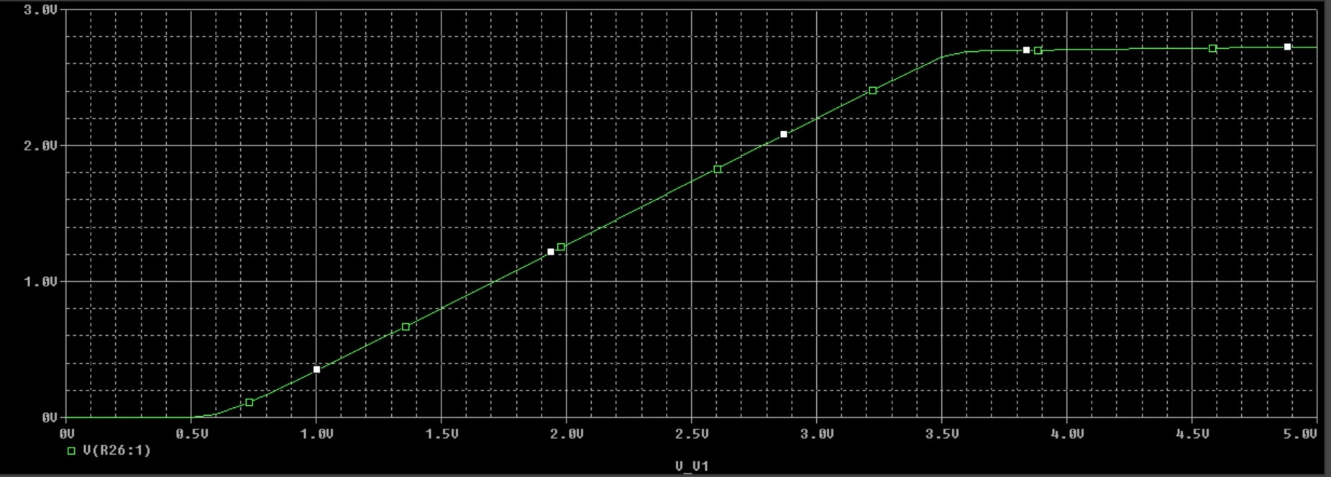
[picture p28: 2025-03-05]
Simulations/stabilitate_cu_vin_set=1.jpg

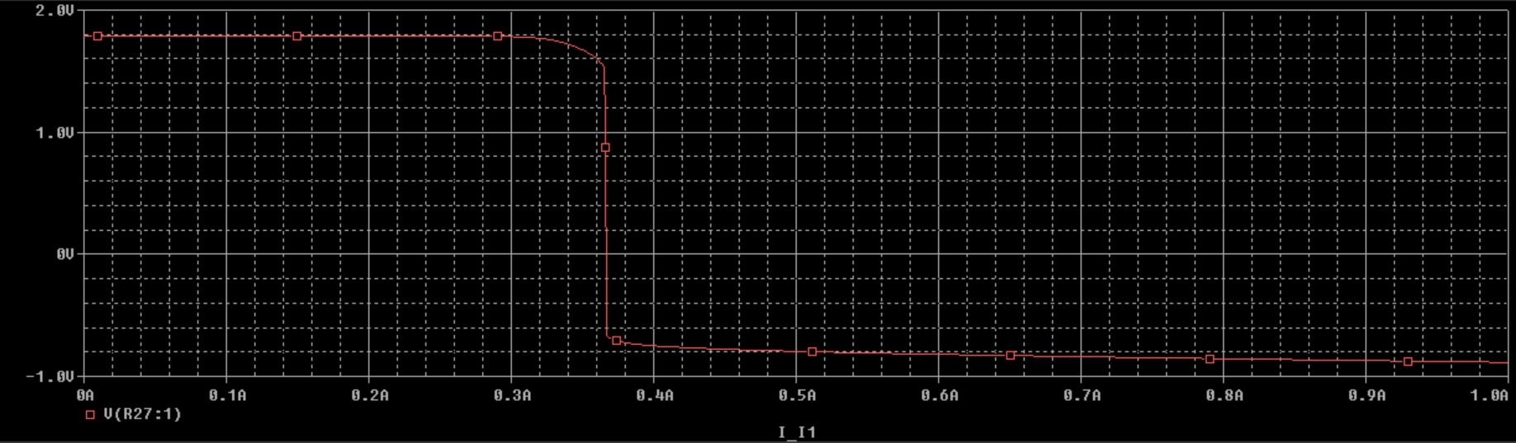
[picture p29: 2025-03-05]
Simulations/protectie_suprasarcina.jpg

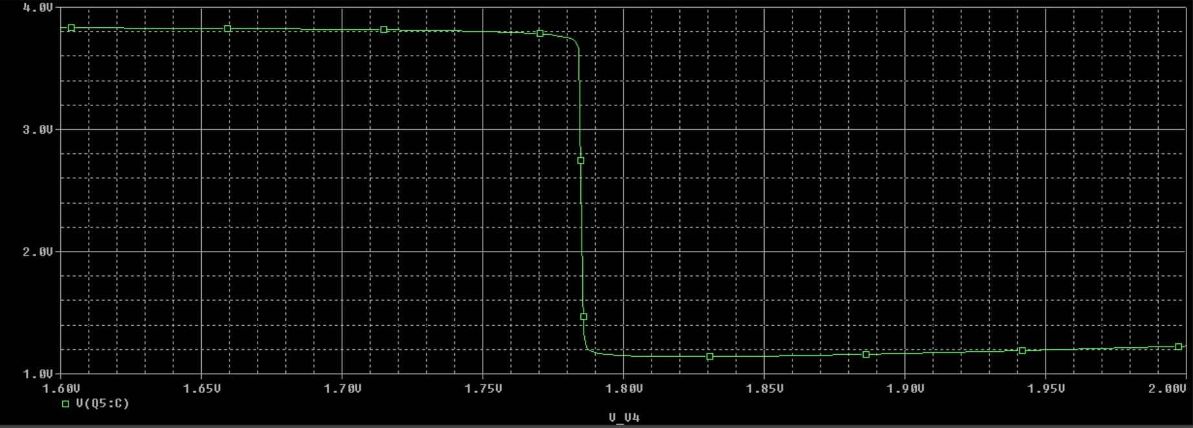
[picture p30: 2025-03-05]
Simulations/amplificare_bucla_deschisa.jpg

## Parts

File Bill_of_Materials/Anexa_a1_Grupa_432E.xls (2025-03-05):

Anexa a1 - Grupa 432E - Tema 7 - Stabilizator de tensiune cu ERS
Nr. Crt. | Nume | Catalog | Cod distrib | Nume prod | Prod | Clasă | Qty fix | Qty final | Qty min | Descriere | Distribuitor | Pret (fara TVA) referinta/buc. TME România | Pret total pe reper (fara TVA) - propus
1 | 0 ohm | (LINK) (http://www.tme.eu/ro/details/smd1206-0r/rezistente-smd-1206/royal-ohm/1206s4j0000t5e/) | 1206S4J0000T5E | 1206S4J0000T5E | SR PASSIVES | rezistor | 0 |  | 0 | Rezistor: thick film; SMD; 1206; 0Ω; 0,25W; ±5%; -55÷125°C | TME România | 0.03841 | 0
2 | 0.47 | (LINK) (http://www.tme.eu/ro/details/smd0805-0r47/rezistente-smd-0805/royal-ohm/0805s8j047kt5e/) | SMD0805-0R47 | 0805S8J047KT5E | ROYAL OHM | rezistor | 20 |  | 0 | Rezistor SMD, chip, 0805, 0.47Ω, ±5%, 0.125W | TME România | 0.01454 | 0.2908
3 | 1 | (LINK) (https://www.tme.eu/ro/details/smd0805-1r/rezistente-smd-0805/royal-ohm/0805s8j010jt5e/) | SMD0805-1R-5% | 0805S8J010JT5E | ROYAL OHM | rezistor | 20 |  | 2 | Rezistor SMD, chip, 0805, 1Ω, ±5%, 0.125W | TME România | 0.01723 | 0.3446
4 | 4.7 | (LINK) (https://www.tme.eu/ro/details/smd0805-4r7/rezistente-smd-0805/royal-ohm/0805s8j047jt5e/) | SMD0805-4R7-5% | 0805S8J047JT5E | ROYAL OHM | rezistor | 10 |  | 0 | Rezistor SMD, chip, 0805, 4.7Ω, ±5%, 0.125W | TME România | 0.01723 | 0.1723
5 | 10 | (LINK) (https://www.tme.eu/ro/details/smd0805-10r/rezistente-smd-0805/royal-ohm/0805s8j0100t5e/) | SMD0805-10R-5% | 0805S8J0100T5E | ROYAL OHM | rezistor | 10 |  | 0 | Rezistor SMD, chip, 0805, 10Ω, ±5%, 0.125W | TME România | 0.01723 | 0.1723
6 | 22 | (LINK) (https://www.tme.eu/ro/details/smd0805-22r-1%25/rezistente-smd-0805/royal-ohm/0805s8f220jt5e/) | SMD0805-22R-1% | 0805S8F220JT5E | ROYAL OHM | rezistor | 20 |  | 1 | Rezistor SMD, chip, 0805, 22Ω, ±1%, 0.125W | TME România | 0.02127 | 0.4254
7 | 33 | (LINK) (https://www.tme.eu/ro/details/smd0805-33r/rezistente-smd-0805/royal-ohm/0805s8j0330t5e/) | SMD0805-33R-5% | 0805S8J0330T5E | ROYAL OHM | rezistor | 20 |  | 2 | Rezistor SMD, chip, 0805, 33Ω, ±5%, 0.125W | TME România | 0.01723 | 0.3446
8 | 51 | (LINK) (http://www.tme.eu/ro/details/rc0805jr-0751r/rezistente-smd-0805/yageo/rc0805jr-0751rl/) | SMD0805-51R-5% | 0805S8J0510T5E | ROYAL OHM | rezistor | 40 |  | 0 | Rezistor SMD, chip, 0805, 51Ω, ±5%, 0.125W | TME România | 0.0261 | 1.044
9 | 68 | (LINK) (http://www.tme.eu/ro/details/smd0805-68r-1%25/rezistente-smd-0805/royal-ohm/0805s8f680jt5e/) | SMD0805-68R-1% | 0805S8F680JT5E | ROYAL OHM | rezistor | 10 |  | 1 | Rezistor SMD, chip, 0805, 68Ω, ±1%, 0.125W | TME România | 0.04662 | 0.4662
10 | 82 | (LINK) (https://www.tme.eu/ro/details/wf08p-82r-5%25/rezistente-smd-0805/walsin/wf08p820jtl/) | SMD0805-82R-5% | WF08P820JTL | WALSIN | rezistor | 20 |  | 0 | Rezistor SMD, chip, 0805, 82Ω, ±5%, 0.125W | TME România | 0.0172 | 0.344
11 | 100 | (LINK) (https://www.tme.eu/ro/details/smd0805-100r/rezistente-smd-0805/royal-ohm/0805s8j0101t5e/) | SMD0805-100R-5% | 0805S8J0101T5E | ROYAL OHM | rezistor | 60 |  | 5 | Rezistor SMD, chip, 0805, 100Ω, ±5%, 0.125W | TME România | 0.01723 | 1.0338
12 | 150 | (LINK) (https://www.tme.eu/ro/details/smd0805-150r/rezistente-smd-0805/royal-ohm/0805s8j0151t5e/) | SMD0805-150R-5% | 0805S8F1500T5E | ROYAL OHM | rezistor | 30 |  | 0 | Rezistor SMD, chip, 0805, 150Ω, ±5%, 0.125W | TME România | 0.01723 | 0.5169
13 | 220 | (LINK) (http://www.tme.eu/ro/details/smd0805-220r-1%25/rezistente-smd-0805/royal-ohm/0805s8f2200t5e/) | SMD0805-220R-5% | 0805S8J0221T5E | ROYAL OHM | rezistor | 30 |  | 0 | Rezistor SMD, chip, 0805, 220Ω, ±5%, 0.125W | TME România | 0.02127 | 0.6381
14 | 330 | (LINK) (https://www.tme.eu/ro/details/smd0805-330r/rezistente-smd-0805/royal-ohm/0805s8j0331t5e/) | SMD0805-330R-5% | 0805S8J0331T5E | ROYAL OHM | rezistor | 30 |  | 0 | Rezistor SMD, chip, 0805, 330Ω, ±5%, 0.125W | TME România | 0.01723 | 0.5169
15 | 470 | (LINK) (https://www.tme.eu/ro/details/smd0805-470r/rezistente-smd-0805/royal-ohm/0805s8j0471t5e/) | SMD0805-470R-5% | 0805S8J0471T5E | ROYAL OHM | rezistor | 30 |  | 0 | Rezistor SMD, chip, 0805, 470Ω, ±5%, 0.125W | TME România | 0.01723 | 0.5169
16 | 510 | (LINK) (https://www.tme.eu/ro/details/smd0805-510r/rezistente-smd-0805/royal-ohm/0805s8j0511t5e/) | SMD0805-510R-5% | 0805S8J0511T5E | YAGEO | rezistor | 30 |  | 1 | Rezistor SMD, chip, 0805, 510Ω, ±5%, 0.125W | TME România | 0.01723 | 0.5169
17 | 680 | (LINK) (https://www.tme.eu/ro/details/smd0805-680r/rezistente-smd-0805/royal-ohm/0805s8j0681t5e/) | SMD0805-680R-5% | 0805S8J0681T5E | ROYAL OHM | rezistor | 30 |  | 0 | Rezistor SMD, chip, 0805, 680Ω, ±5%, 0.125W | TME România | 0.01723 | 0.5169
18 | 820 | (LINK) (https://www.tme.eu/ro/details/smd0805-820r/rezistente-smd-0805/royal-ohm/0805s8j0821t5e/) | SMD0805-820R-5% | 0805S8J0821T5E | ROYAL OHM | rezistor | 30 |  | 0 | Rezistor SMD, chip, 0805, 820Ω, ±5%, 0.125W | TME România | 0.01723 | 0.5169
19 | 910 | (LINK) (https://www.tme.eu/ro/details/rc0805jr-07910r/rezistente-smd-0805/yageo/rc0805jr-07910rl/) | SMD0805-910R-5% | RC0805JR-07910RL | YAGEO | rezistor | 40 |  | 0 | Rezistor SMD, chip, 0805, 910Ω, ±5%, 0.125W | TME România | 0.0261 | 1.044
20 | 1k | (LINK) (https://www.tme.eu/ro/details/smd0805-1k/rezistente-smd-0805/royal-ohm/0805s8j0102t5e/) | SMD0805-1K-5% | 0805S8J0102T5E | ROYAL OHM | rezistor | 100 |  | 2 | Rezistor SMD, chip, 0805, 1kΩ, ±5%, 0.125W | TME România | 0.01723 | 1.723
21 | 1.5k | (LINK) (https://www.tme.eu/ro/details/wf08p-1k5-5%25/rezistente-smd-0805/walsin/wf08p152jtl/) | SMD0805-1K5-5% | WF08P152JTL | WALSIN | rezistor | 40 |  | 0 | Rezistor SMD, chip, 0805, 1.5kΩ, ±5%, 0.125W | TME România | 0.0172 | 0.688
22 | 1.8k | (LINK) (https://www.tme.eu/ro/details/smd0805-1k8/rezistente-smd-0805/royal-ohm/0805s8j0182t5e/) | SMD0805-1K8-5% | 0805S8J0182T5E | ROYAL OHM | rezistor | 30 |  | 0 | Rezistor SMD, chip, 0805, 1.8kΩ, ±5%, 0.125W | TME România | 0.01723 | 0.5169
23 | 2k | (LINK) (https://www.tme.eu/ro/details/smd0805-2k/rezistente-smd-0805/royal-ohm/0805s8j0202t5e/) | SMD0805-2K-5% | 0805S8J0202T5E | ROYAL OHM | rezistor | 80 |  | 0 | Rezistor SMD, chip, 0805, 2kΩ, ±5%, 0.125W | TME România | 0.01723 | 1.3784
24 | 2.2k | (LINK) (https://www.tme.eu/ro/details/smd0805-2k2/rezistente-smd-0805/royal-ohm/0805s8j0222t5e/) | SMD0805-2K2-5% | 0805S8J0222T5E | ROYAL OHM | rezistor | 30 |  | 0 | Rezistor SMD, chip, 0805, 2.2kΩ, ±5%, 0.125W | TME România | 0.01723 | 0.5169
25 | 2.7k | (LINK) (https://www.tme.eu/ro/details/smd0805-2k7/rezistente-smd-0805/royal-ohm/0805s8j0272t5e/) | SMD0805-2K7-5% | 0805S8F2701T5E | ROYAL OHM | rezistor | 30 |  | 1 | Rezistor SMD, chip, 0805, 2.7kΩ, ±5%, 0.125W | TME România | 0.01723 | 0.5169
26 | 3.3k | (LINK) (https://www.tme.eu/ro/details/smd0805-3k3/rezistente-smd-0805/royal-ohm/0805s8j0332t5e/) | SMD0805-3K3-5% | 0805S8J0332T5E | ROYAL OHM | rezistor | 20 |  | 0 | Rezistor SMD, chip, 0805, 3.3kΩ, ±5%, 0.125W | TME România | 0.01723 | 0.3446
27 | 3.9k | (LINK) (https://www.tme.eu/ro/details/smd0805-3k9/rezistente-smd-0805/royal-ohm/0805s8j0392t5e/) | SMD0805-3K9-5% | 0805S8J0392T5E | ROYAL OHM | rezistor | 20 |  | 0 | Rezistor SMD, chip, 0805, 3.9kΩ, ±5%, 0.125W | TME România | 0.01723 | 0.3446
28 | 4.7k | (LINK) (https://www.tme.eu/ro/details/smd0805-4k7/rezistente-smd-0805/royal-ohm/0805s8j0472t5e/) | SMD0805-4K7-5% | 0805S8J0472T5E | ROYAL OHM | rezistor | 30 |  | 0 | Rezistor SMD, chip, 0805, 4.7kΩ, ±5%, 0.125W | TME România | 0.01723 | 0.5169
29 | 5.6k | (LINK) (https://www.tme.eu/ro/details/smd0805-5k6/rezistente-smd-0805/royal-ohm/0805s8j0562t5e/) | SMD0805-5K6-5% | 0805S8J0562T5E | ROYAL OHM | rezistor | 40 |  | 0 | Rezistor SMD, chip, 0805, 5.6kΩ, ±5%, 0.125W | TME România | 0.01723 | 0.6892
30 | 6.8k | (LINK) (https://www.tme.eu/ro/details/rc0805jr-076k8/rezistente-smd-0805/yageo/rc0805jr-076k8l/) | SMD0805-6K8-5% | RC0805JR-076K8L | YAGEO | rezistor | 20 |  | 0 | Rezistor SMD, chip, 0805, 6.8kΩ, ±5%, 0.125W | TME România | 0.0261 | 0.522
31 | 8.2k | (LINK) (https://www.tme.eu/ro/details/smd0805-8k2/rezistente-smd-0805/royal-ohm/0805s8j0822t5e/) | SMD0805-8K2-5% | 0805S8J0822T5E | ROYAL OHM | rezistor | 30 |  | 0 | Rezistor SMD, chip, 0805, 8.2kΩ, ±5%, 0.125W | TME România | 0.01723 | 0.5169
32 | 9.1k | (LINK) (https://www.tme.eu/ro/details/smd0805-9k1/rezistente-smd-0805/royal-ohm/0805s8j0912t5e/) | SMD0805-9K1-5% | 0805S8J0912T5E | ROYAL OHM | rezistor | 20 |  | 0 | Rezistor SMD, chip, 0805, 9.1kΩ, ±5%, 0.125W | TME România | 0.01723 | 0.3446
33 | 10k | (LINK) (https://www.tme.eu/ro/details/smd0805-10k/rezistente-smd-0805/royal-ohm/0805s8j0103t5e/) | SMD0805-10K-5% | 0805S8J0103T5E | ROYAL OHM | rezistor | 100 |  | 0 | Rezistor SMD, chip, 0805, 10kΩ, ±5%, 0.125W | TME România | 0.01723 | 1.723
34 | 15k | (LINK) (https://www.tme.eu/ro/details/smd0805-15k/rezistente-smd-0805/royal-ohm/0805s8j0153t5e/) | SMD0805-15K-5% | 0805S8J0153T5E | ROYAL OHM | rezistor | 30 |  | 0 | Rezistor SMD, chip, 0805, 15kΩ, ±5%, 0.125W | TME România | 0.01723 | 0.5169
35 | 22k | (LINK) (https://www.tme.eu/ro/details/smd0805-22k/rezistente-smd-0805/royal-ohm/0805s8j0223t5e/) | SMD0805-22K-5% | 0805S8J0223T5E | ROYAL OHM | rezistor | 30 |  | 1 | Rezistor SMD, chip, 0805, 22kΩ, ±5%, 0.125W | TME România | 0.01723 | 0.5169
36 | 47k | (LINK) (http://www.tme.eu/ro/details/smd0805-47k/rezistente-smd-0805/royal-ohm/0805s8j0473t5e/) | SMD0805-47K-5% | 0805S8J0473T5E | ROYAL OHM | rezistor | 40 |  | 0 | Rezistor: thick film; SMD; 0805; 47kΩ; 0,125W; ±5%; -55÷125°C | TME România | 0.01723 | 0.6892
37 | 68k | (LINK) (https://www.tme.eu/ro/details/smd0805-68k/rezistente-smd-0805/royal-ohm/0805s8j0683t5e/) | SMD0805-68K-5% | 0805S8J0683T5E | ROYAL OHM | rezistor | 20 |  | 0 | Rezistor SMD, chip, 0805, 68kΩ, ±5%, 0.125W | TME România | 0.01723 | 0.3446
38 | 100k | (LINK) (https://www.tme.eu/ro/details/smd0805-100k/rezistente-smd-0805/royal-ohm/0805s8j0104t5e/) | SMD0805-100K-5% | 0805S8J0104T5E | ROYAL OHM | rezistor | 100 |  | 0 | Rezistor SMD, chip, 0805, 100kΩ, ±5%, 0.125W | TME România | 0.01723 | 1.723
39 | 150k | (LINK) (http://www.tme.eu/ro/details/smd0805-150k/rezistente-smd-0805/royal-ohm/0805s8j0154t5e/) | SMD0805-150K-5% | 0805S8J0154T5E | ROYAL OHM | rezistor | 30 |  | 0 | Rezistor SMD, chip, 0805, 150kΩ, ±5%, 0.125W | TME România | 0.01723 | 0.5169
40 | 180k | (LINK) (http://www.tme.eu/ro/details/smd0805-180k/rezistente-smd-0805/royal-ohm/0805s8j0184t5e/) | SMD0805-180K-5% | 0805S8J0184T5E | ROYAL OHM | rezistor | 30 |  | 0 | Rezistor SMD, chip, 0805, 180kΩ, ±5%, 0.125W | TME România | 0.01723 | 0.5169
41 | 220k | (LINK) (https://www.tme.eu/ro/details/smd0805-220k/rezistente-smd-0805/royal-ohm/0805s8j0224t5e/) | SMD0805-220K-5% | 0805S8J0224T5E | ROYAL OHM | rezistor | 30 |  | 0 | Rezistor SMD, chip, 0805, 220kΩ, ±5%, 0.125W | TME România | 0.01723 | 0.5169
42 | 330k | (LINK) (https://www.tme.eu/ro/details/smd0805-330k/rezistente-smd-0805/royal-ohm/0805s8j0334t5e/) | SMD0805-330K-5% | 0805S8J0334T5E | ROYAL OHM | rezistor | 30 |  | 0 | Rezistor SMD, chip, 0805, 330kΩ, ±5%, 0.125W | TME România | 0.01723 | 0.5169
43 | 390k | (LINK) (https://www.tme.eu/ro/details/smd0805-390k/rezistente-smd-0805/royal-ohm/0805s8j0394t5e/) | SMD0805-390K-5% | 0805S8J0394T5E | ROYAL OHM | rezistor | 30 |  | 0 | Rezistor SMD, chip, 0805, 390kΩ, ±5%, 0.125W | TME România | 0.01723 | 0.5169
44 | 510k | (LINK) (https://www.tme.eu/ro/details/smd0805-510k/rezistente-smd-0805/royal-ohm/0805s8j0514t5e/) | SMD0805-510K-5% | 0805S8J0514T5E | ROYAL OHM | rezistor | 30 |  | 0 | Rezistor SMD, chip, 0805, 510kΩ, ±5%, 0.125W | TME România | 0.01723 | 0.5169
45 | 1M | (LINK) (https://www.tme.eu/ro/details/crcw08051m00jntabc/rezistente-smd-0805/vishay/) | SMD0805-1M-5% | CRCW08051M00JNTABC | VISHAY | rezistor | 0 |  | 0 | Rezistor SMD, chip, 0805, 1MΩ, ±5%, 0.125W | TME România | 0.01151 | 0
46 | 2M | (LINK) (http://www.tme.eu/ro/details/smd0805-2m/rezistente-smd-0805/royal-ohm/0805waj-2m-t5e/) | SMD0805-2M7 5% | 0805WAJ 2M T5E | ROYAL OHM | rezistor | 0 |  | 0 | Rezistor SMD, chip, 0805, 2MΩ, ±1%, 0.125W | TME România | 0.01723 | 0
47 | 5,1M | (LINK) (http://www.tme.eu/ro/details/smd0805-5m1/rezistente-smd-0805/royal-ohm/0805s8j0515t5e/) | SMD0805-5M1 5% | RC0805FR-075M1 | Yageo | rezistor | 0 |  | 0 | Rezistor SMD, chip, 0805, 5.1MΩ, ±1%, 0.125W | TME România | 0.01723 | 0
48 | 10M | (LINK) (https://www.tme.eu/ro/details/0805s8j0106t5e/rezistente-smd-0805/royal-ohm/) | SMD0805-10M 5% | 0805S8J0106T5E | ROYAL OHM | rezistor | 0 |  | 0 | Rezistor SMD, chip, 0805, 10MΩ, ±5%, 0.125W | TME România | 0.01723 | 0
49 | 100ohm | (LINK) (https://www.tme.eu/ro/details/ts53yl100r/trimere-smd-cu-o-singura-tura/vishay/ts53yl101mr10/) | 1804GSMD-100R | 1804GSMD-100R | SR PASSIVES | potențiometru | 15 |  | 0 | Potențiome-tru liniar, simplă tură, SMD, 100Ω, ±10%, 100ppm/°C, 0.25W | TME România | 3.77 | 56.55
50 | 500ohm | (LINK) (https://www.tme.eu/ro/details/ts53yl500r/trimere-smd-cu-o-singura-tura/vishay/ts53yl501mr10/) | 1804GSMD-500R | 1804GSMD-500R | VISHAY | potențiometru | 0 |  | 0 | Potențiome-tru liniar, simplă tură, SMD, 500Ω, ±10%, 100ppm/°C, 0.25W | TME România | 2.19 | 0
51 | 2k | (LINK) (https://www.tme.eu/ro/details/ts53yl2k/trimere-smd-cu-o-singura-tura/vishay/ts53yl202mr10/) | TS53YL202MR10 | TS53YL202MR10 | VISHAY | potențiometru | 0 |  | 0 | Potențiome-tru liniar, simplă tură, SMD, 2kΩ, ±20%, 100ppm/°C, 0.25W | TME România | 2.84 | 0
52 | 5k | (LINK) (http://www.tme.eu/ro/details/3314g-1-502e/trimere-smd-cu-o-singura-tura/bourns/) | 3314G-1-502E | 3314G-1-502E | BOURNS | potențiometru | 40 |  | 1 | Potențiome-tru liniar, simplă tură, SMD, 5kΩ, ±20%, 100ppm/°C, 0.25W | TME România | 3.45 | 138
53 | 10k | (LINK) (http://www.tme.eu/ro/details/3314g-1-103e/trimere-smd-cu-o-singura-tura/bourns/) | 3314G-1-103E | 3314G-1-103E | BOURNS | potențiometru | 20 |  | 1 | Potențiome-tru liniar, simplă tură, SMD, 10kΩ, ±20%, 100ppm/°C, 0.25W | TME România | 3.0573 | 61.146
54 | 50k | (LINK) (http://www.tme.eu/ro/details/3314g-1-503e/trimere-smd-cu-o-singura-tura/bourns/) | 3314G-1-503E | 3314G-1-503E | BOURNS | potențiometru | 0 |  | 0 | Potențiome-tru liniar, simplă tură, SMD, 50kΩ, ±20%, 100ppm/°C, 0.25W | TME România | 2.84 | 0
55 | 100k | (LINK) (http://www.tme.eu/ro/details/ts53yl100k/trimere-smd-cu-o-singura-tura/vishay/ts53yl104mr10/) | TS53YL104MR10 | TS53YL104MR10 | VISHAY | potențiometru | 10 |  | 0 | Potențiome-tru liniar, simplă tură, SMD, 100kΩ, ±20%, 100ppm/°C, 0.25W | TME România | 2.61 | 26.1
56 | 500k | (LINK) (http://www.tme.eu/ro/details/3314g-1-504e/trimere-smd-cu-o-singura-tura/bourns/) | 3314G-1-504E | 3314G-1-504E | BOURNS | potențiometru | 0 |  | 0 | Potențiome-tru liniar, simplă tură, SMD, 500kΩ, ±10%, 100ppm/°C, 0.25W | TME România | 2.8802 | 0
 | TOTAL - Componente pasive (rezistoare de valori fixe şi reglabile) |  |  |  |  |  |  |  |  | FARA TVA = | 308.4514 | CU TVA= | 382.479736
57 | 4.7pF | (LINK) (http://www.tme.eu/ro/details/cc0805crnpo94r7/condensatoare-mlcc-smd-0805/yageo/cc0805crnpo9bn4r7/) | CC0805CRNPO9BN4R7 | CC0805CRNPO9BN4R7 | YAGEO | condensator | 20 |  | 0 | ceramic; MLCC; 4,7pF; 50V; C0G; ±0,25pF; SMD; 0805 | TME România | 0.16643 | 3.3286
58 | 10pF | (LINK) (http://www.tme.eu/ro/details/cc0805jrnpo9100/condensatoare-mlcc-smd-0805/yageo/cc0805jrnpo9bn100/) | CC0805JRNPO9BN100 | CC0805JRNPO9BN100 | YAGEO | condensator | 20 |  | 0 | ceramic; MLCC; 10pF; 50V; C0G; ±5%; SMD; 0805 | TME România | 0.1649 | 3.298
59 | 47pF | (LINK) (http://www.tme.eu/ro/details/cl21c470jbannnc/condensatoare-mlcc-smd-0805/samsung/) | CL21C470JBANNNC | CL21C470JBANNNC | SAMSUNG | condensator | 20 |  | 0 | Condensator: ceramic; MLCC; 47pF; 50V; C0G; ±5%; SMD; 0805; -55÷125°C | TME România | 0.11097 | 2.2194
21wqaz1 | 100pF | (LINK) (http://www.tme.eu/ro/details/cl21c101jbannnc/condensatoare-mlcc-smd-0805/samsung/) | CL21C101JBANNNC | CL21C101JBANNNC | SAMSUNG | condensator | 20 |  | 0 | Condensator: ceramic; MLCC; 100pF; 50V; C0G; ±5%; SMD; 0805 | TME România | 0.05427 | 1.0854
61 | 470pF | (LINK) (https://www.tme.eu/ro/details/cl21c471jbannnc/condensatoare-mlcc-smd-0805/samsung/) | CL21C471JBANNNC | CL21C471JBANNNC | SAMSUNG | condensator | 20 |  | 0 | Condensator: ceramic; MLCC; 470pF; 50V; X7R; ±10%; SMD; 0805 | TME România | 0.12123 | 2.4246
62 | 1nF | (LINK) (https://www.tme.eu/ro/details/cc0805jrnpo9102/condensatoare-mlcc-smd/yageo/cc0805jrnpo9bn102/) | CL21C102JBCNNNC | CL21C102JBCNNNC | SAMSUNG | condensator | 0 |  | 0 | Condensator MLCC, SMD, 0805, 1nF, ±5%, 50V, C0G | TME România | 0.06487 | 0
63 | 2.2nF | (LINK) (https://www.tme.eu/ro/details/cl21b222jbannnc/condensatoare-mlcc-smd-0805/samsung/) | CL21B222JBANNNC | CL21B222JBANNNC | SAMSUNG | condensator | 0 |  | 0 | Condensator: ceramic; MLCC; 2,2nF; 50V; X7R; ±10%; SMD; 0805 | TME România | 0.1485 | 0
64 | 4.7nF | (LINK) (https://www.tme.eu/ro/details/cl21b472kbannnc/condensatoare-mlcc-smd-0805/samsung/) | CL21B472KBANNNC | CL21B472KBANNNC | SAMSUNG | condensator | 0 |  | 0 | Condensator MLCC, SMD, 0805, 4.7nF, ±5%, 50V, X7R | TME România | 0.08943 | 0
65 | 5.6nF | (LINK) (https://www.tme.eu/ro/details/cl21b562kbannnc/condensatoare-mlcc-smd-0805/samsung/) | CL21B562KBANNNC | CL21B562KBANNNC | SAMSUNG | condensator | 0 |  | 0 | Condensator MLCC, SMD, 0805, 5.6nF, ±5%, 50V, X7R | TME România | 0.04517 | 0
66 | 10nF | (LINK) (https://www.tme.eu/ro/details/cl21b103kbannnd/condensatoare-mlcc-smd-0805/samsung/) | CL21B103KBANNND | CL21B103KBANNND | SAMSUNG | condensator | 40 |  | 0 | Condensator MLCC, SMD, 0805, 10nF, ±5%, 50V, X7R | TME România | 0.06093 | 2.4372
67 | 22nF | (LINK) (http://www.tme.eu/ro/details/cl21b223kcfnnne/condensatoare-mlcc-smd-0805/samsung/) | CL21B223KBANNNC | CL21B223KBANNNC | SAMSUNG | condensator | 0 |  | 0 | Condensator: ceramic; MLCC; 22nF; 100V; X7R; ±10%; SMD; 0805 | TME România | 0.13823 | 0
68 | 33nF | (LINK) (https://www.tme.eu/ro/details/vj0805y333kxacw1bc/condensatoare-mlcc-smd-0805/vishay/) | VJ0805Y333KXACW1BC | VJ0805Y333KXACW1BC | VISHAY | condensator | 0 |  | 0 | Condensator: ceramic; MLCC; 33nF; 50V; X7R; ±10%; SMD; 0805 | TME România | 0.05417 | 0
69 | 100nF | (LINK) (https://www.tme.eu/ro/details/cl21b104kbcnnnc/condensatoare-mlcc-smd/samsung/) | CL21B104KBCNNNC | CL21B104KBCNNNC | SAMSUNG | condensator | 40 |  | 1 | ceramic; MLCC; 100nF; 50V; X7R; ±10%; SMD; 0805 | TME România | 0.3759 | 15.036
70 | 220nF | (LINK) (http://www.tme.eu/ro/details/cl21b224kafnnne/condensatoare-mlcc-smd-0805/samsung/) | CL21B224KAFNNNE | CL21B224KAFNNNE | SAMSUNG | condensator | 0 |  | 0 | Condensator: ceramic; MLCC; 220nF; 25V; X7R; ±10%; SMD; 0805 | TME România | 0.10247 | 0
71 | 330nF | (LINK) (https://www.tme.eu/ro/details/grm219r71h334ka88d/condensatoare-mlcc-smd-0805/murata/) | GRM219R71H334KA88D | GRM219R71H334KA88D | MURATA | condensator | 0 |  | 0 | Condensator: ceramic; MLCC; 330nF; 50V; X7R; ±10%; SMD; 0805 | TME România | 0.5972 | 0
72 | 470nF | (LINK) (https://www.tme.eu/ro/details/cc0805mry5v8474/condensatoare-mlcc-smd-0805/yageo/cc0805mry5v8bb474/) | CC0805MRY5V8474 | CC0805MRY5V8BB474 | YAGEO | condensator | 0 |  | 0 | Condensator: ceramic; MLCC; 470nF; 50V; Y5V; -20÷+80%; SMD; 0805 | TME România | 0.0758 | 0
73 | 1uF | (LINK) (https://www.tme.eu/ro/details/cl21b105kbfnnng/condensatoare-mlcc-smd-0805/samsung/) | CL21B105KBFNNNG | CL21B105KBFNNNG | SAMSUNG | condensator | 20 |  | 0 | Condensator: ceramic; MLCC; 1uF; 50V; X7R; ±20%; SMD; 0805 | TME România | 0.25253 | 5.0506
74 | 2.2uF | (LINK) (https://www.tme.eu/ro/details/grm21br61h225ka73l/condensatoare-mlcc-smd-0805/murata/) | GRM21BR61H225KA73L | GRM21BR61H225KA73L | MURATA | condensator | 20 |  | 0 | Condensator: ceramic; MLCC; 2,2uF; 25V; X5R; ±10%; SMD; 0805 | TME România | 0.4486 | 8.972
75 | 4.7uF | (LINK) (https://www.tme.eu/ro/details/cl21a475kaqnnng/condensatoare-mlcc-smd-0805/samsung/) | CL21A475KAQNNNG | CL21A475KAQNNNG | SAMSUNG | condensator | 20 |  | 0 | ceramic; MLCC; 4,7uF; 25V; X5R; ±10%; SMD; 0805 | TME România | 0.25373 | 5.0746
76 | 10uF | (LINK) (https://www.tme.eu/ro/details/eee1ha100sp/condensatoare-electrolitice-smd/panasonic/) | EEE1HA100SP | EEE1HA100SP | PANASONIC | condensator | 16 |  | 0 | Condensator: electrolitic; SMD; 10uF; 50V | TME România | 0.2284 | 3.6544
 | TOTAL - Componente pasive (condensatoare) |  |  |  |  |  |  |  |  | FARA TVA = | 52.5808 | CU TVA= | 65.200192
77 | 4148 | (LINK) (http://www.tme.eu/ro/details/1n4148-0805/diode-universale-smd/dc-components/cd4148ws0805c/) | 1N4148-0805 | CD4148WS(0805C) | DC Components | diodă pn | 40 |  | 0 | Diodă comutație, SMD, 0805, 300mA, 100V | TME România | 0.04555 | 1.822
78 | LED | (LINK) (https://www.tme.eu/ro/details/of-smd2012b/diode-led-smd-colorate/optoflash/) | OF-SMD2012B | OF-SMD2012B | OPTOFLASH | LED | 15 |  | 1 | LED albastru, SMD, 0805, 150-200mcd, 476nm, 120° | TME România | 0.1264 | 1.896
79 | 2.7V | (LINK) (https://www.tme.eu/ro/details/bzx84-c2v7.215/diode-zener-smd/nexperia/bzx84-c2v7-215/) | BZX84C2V7 | BZX84-C2V7LT1G | ON Semiconductor | diodă Zener | 5 |  | 1 | Diodă Zener, SMD, SOT23, 2,7V, ±5%, 0.25W | TME România | 0.05732 | 0.2866
80 | 5.1V | (LINK) (https://www.tme.eu/ro/details/bzx84-c5v1.215/diode-zener-smd/nexperia/) | BZX84C5V1 | BZX84-C5V1 | NEXPERIA | diodă Zener | 10 |  | 0 | Diodă Zener, SMD, SOT23, 5,1V, ±5%, 0.3W | TME România | 0.06245 | 0.6245
81 | 5.6V | (LINK) (https://www.tme.eu/ro/details/bzx84b5v6-dio/diode-zener-smd/diotec-semiconductor/bzx84b5v6/) | BZX84B5V6 | BZX84B5V6 | DIOTEC SEMICONDUCTOR | diodă Zener | 10 |  | 0 | Diodă Zener, SMD, SOT23, 5,6V, ±5%, 0.3W | TME România | 0.0839 | 0.839
82 | 6.2V | (LINK) (https://www.tme.eu/ro/details/bzx84-c6v2.215/diode-zener-smd/nexperia/) | BZX84C6V2 | BZX84-C6V2 | NEXPERIA | diodă Zener | 5 |  | 0 | Diodă Zener, SMD, SOT23, 6.2V, ±5%, 0.3W | TME România | 0.06618 | 0.3309
83 | 6.8V | (LINK) (https://www.tme.eu/ro/details/bzx84-c6v8.215/diode-zener-smd/nexperia/) | BZX84C6V8 | BZX84-C6V8 | NEXPERIA | diodă Zener | 0 |  | 0 | Diodă Zener, SMD, SOT23, 6.8V, ±5%, 0.3W | TME România | 0.05686 | 0
84 | 8.2V | (LINK) (https://www.tme.eu/ro/details/bzx84-c8v2.215/diode-zener-smd/nexperia/) | BZX84C8V2 | BZX84-C8V2 | NEXPERIA | diodă Zener | 5 |  | 0 | Diodă Zener, SMD, SOT23, 8.2V, ±5%, 0.3W | TME România | 0.05686 | 0.2843
85 | 10V | (LINK) (https://www.tme.eu/ro/details/bzx84-c10.215/diode-zener-smd/nexperia/) | BZX84C10 | BZX84-C10 | NEXPERIA | diodă Zener | 5 |  | 0 | Diodă Zener, SMD, SOT23, 10V, ±5%, 0.3W | TME România | 0.05686 | 0.2843
86 | PNP | (LINK) (http://www.tme.eu/ro/details/bc856b-dio/tranzistori-smd-pnp/diotec-semiconductor/bc856b/) | BC856B | BC856B | DIOTEC | tranzistor bipolar | 80 |  | 0 | Tranzistor bipolar PNP, SMD, SOT23, 80V, 100mA | TME România | 0.04055 | 3.244
87 | NPN | (LINK) (https://www.tme.eu/ro/details/bc846b-dio/tranzistori-smd-npn/diotec-semiconductor/bc846b/) | BC846B | BC846B | DIOTEC | tranzistor bipolar | 80 |  | 7 | Tranzistor bipolar NPN, SMD, SOT23, 65V, 100mA | TME România | 0.03379 | 2.7032
89 | N-JFET | (LINK) (http://www.tme.eu/ro/details/mmbfj309lt1g/tranzistori-canal-n-smd/on-semiconductor/) | MMBFJ309LT1G | MMBFJ309LT1G | ON Semiconductor | tranzistor NJFET | 40 |  | 0 | Tranzistor N-JFET, SMD, SOT23, 25V, 30mA | TME România | 0.8063 | 32.252
90 | P-JFET | (LINK) (http://www.tme.eu/ro/details/mmbfj177lt1g/tranzistori-canal-p-smd/on-semiconductor/) | MMBFJ177LT1G | MMBFJ177LT1G | ON Semiconductor | tranzistor PJFET | 15 |  | 0 | Tranzistor P-JFET, SMD, SOT23, 30V, 20mA | TME România | 0.8808 | 13.212
91 | NPN | (LINK) (http://www.tme.eu/ro/details/bc817-25-dio/tranzistori-smd-npn/diotec-semiconductor/bc817-25/) | BC817-25-DIO | BC817-25-DIO | NXP | tranzistor bipolar | 10 |  | 0 | Tranzistor bipolar NPN, SMD, SOT23, 45V, 800mA | TME România | 0.0494 | 0.494
93 | PNP | (LINK) (http://www.tme.eu/ro/details/bc807-25-dio/tranzistori-smd-pnp/diotec-semiconductor/bc807-25/) | BC807-25-DIO | BC807-25-DIO | NXP | tranzistor bipolar | 10 |  | 3 | Tranzistor bipolar PNP, SMD, SOT23, 45V, 800mA | TME România | 0.05406 | 0.5406
94 | NPN | (LINK) (http://www.tme.eu/ro/details/mjd31cg/tranzistori-smd-npn/on-semiconductor/) | MJD31CG | MJD31CG | ON Semiconductor | tranzistor bipolar | 20 |  | 0 | Tranzistor bipolar NPN, SMD, DPACK, 100V, 3A, 15W | TME România | 0.7037 | 14.074
96 | PNP | (LINK) (http://www.tme.eu/ro/details/mjd32cg/tranzistori-smd-pnp/on-semiconductor/) | MJD32CG | MJD32CG | ON Semiconductor | tranzistor bipolar | 20 |  | 0 | Tranzistor bipolar PNP, SMD, DPACK, 100V, 3A, 15W | TME România | 0.783 | 15.66
97 | Nmos | (LINK) (http://www.tme.eu/ro/details/irfr120npbf/tranzistori-canal-n-smd/international-rectifier/) | IRFR120NPBF | IRFR120NPBF | International Rectifier | tranzistor NMOS | 10 |  | 0 | Tranzistor N-MOSFET, SMD, DPAK, 100V, 9.1A, 20V, 39W | TME România | 1.03 | 10.3
 | TOTAL - Componente semiconductoare (tranzistoare bipolare şi cu efect de câmp, diode, LED, etc.) |  |  |  |  |  |  |  |  | FARA TVA = | 126.1474 | CU TVA= | 156.422776
98 | Conn2p | (LINK) (http://www.tme.eu/ro/details/zl301-40p/pini-cu-benzi-si-soclu/ninigi/) | ZL301-40P | ZL301-40P | NINIGI | Sir pini, pas 2,54mm, SMD | 0 |  | 0 | Sir pini, pas 2,54mm, SMD, tip tata, bareta de 40 pini | TME România | 2.3027 | 0
99 | FUSE | (LINK) (http://www.tme.eu/ro/details/3413.0116.11/sigurante-smd-1206-ultrarapide/schurter/) | 3413.0116.11 | 3413.0116.11 | SCHURTER | sigu-ranță | 0 |  | 0 | Siguranță sticlă, SMD, 1206, 1.25A, 48mΩ | TME România | 0 | 0
 | Total - Conectică, sigurante fuzibile, etc. |  |  |  |  |  |  |  |  | FARA TVA = | 0 | CU TVA= | 0
 | Total general |  |  |  |  |  |  |  |  | FARA TVA = | 487.1796 | CU TVA= | 579.743724

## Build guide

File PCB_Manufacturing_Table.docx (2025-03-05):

General info document for PCB manufacturing
No. | Item Name | File Name | | | | | | Info / Remarks / Notes
| BOARD
1 | Board Name / Number | LAYOUT.brd | | | | | | -
2 | Revision Date | 23 NOV 2024 | | | | | | -
3 | Board Size | 40 x 40 mm² | | | | | | -
4 | Board Quantity | 1 | | | | | | -
5 | Material / Dielectric Type | FR4 | | | | | | -
6 | Board Thickness | 1.6 mm | | | | | | -
7 | Copper Thickness | 18 μm | | | | | | -
| LAYERS
8 | Number of Electrical Layers | 2 | | | | | | -
9 | Copper Layer TOP | TOP.art | | | | | | -
10 | Copper Layer BOTTOM | BOTTOM.art | | | | | | -
11 | Copper GND Plane | - | | | | | | -
12 | Copper PWR Plane | - | | | | | | -
13 | Copper INNER 1 | - | | | | | | -
14 | Copper INNER 2 | - | | | | | | -
15 | Solder Mask TOP | SMTOP.art | | | | | | -
16 | Solder Mask BOTTOM | SMBOT.art | | | | | | -
17 | Solder Paste TOP | SPTOP.art | | | | | | -
18 | Solder Paste BOTTOM | - | | | | | | -
19 | Peelable Mask TOP | - | | | | | | -
20 | Peelable Mask BOTTOM | - | | | | | | -
21 | Silk Screen TOP | SSTOP.art | | | | | | -
22 | Silk Screen BOTTOM | - | | | | | | -
23 | Board Outline | BO.art | | | | | | -
24 | Fabrication Drawing | FAB.art | | | | | | -
| MILLING & DRILLING
25 | Mill Drawing | - | | | | | | -
26 | Drill Drawing | - | | | | | | -
27 | N.C. Drill (for both PH & NPH) | DRILL.drl | | | | | | -
28 | N.C. Drill / Plated Holes (PH) | 12 | | | | | | -
29 | N.C. Drill / Non-Plated Holes (PH) | - | | | | | | -
| FINISHING
30 | Panelisation | - | | | | | | -
31 | Electrical Test | - | | | | | | -
32 | Copper Finishing | x | HASL | | OSP | | | ENIG
33 | Board Outline Machining | | Routing | | Milling | | x | V-Cutting
34 | Final remarks | - | | | | -
